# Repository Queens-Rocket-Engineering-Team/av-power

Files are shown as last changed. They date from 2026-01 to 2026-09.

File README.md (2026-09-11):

# Avionics Power Delivery (Power Module, Backplane, Screw Switch, etc)
> 2023-2026 Season - Power Delivery Projects

-  Repo contains board's **firmware**, **schematics**, and related **documentation and datasheets**.
-  The **Main** branch contains current functional hardware/software
-  **Branches** contain board revisions/versions or planned features/fixes.
-  If you're contributing, **make sure you're working in a branch other than Main**

### Folder Structure
- [`/Schematics`](./Schematics/) : PCB design files (KiCad V8)  
- [`/Firmware`](./Firmware/) : Arduino C/C++ code (for STM)
- [`/Datasheets`](./Datasheets/) : Datasheets and reference materials

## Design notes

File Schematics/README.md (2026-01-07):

# Schematics

This directory contains all schematics involved in this iteration of the Avionics Power Deliver system.

## Backplane
- Single, large PCB
- Connects all stack "modules" (PCBs)
- Allows communication between modules
- Cleaner routing for power

## Power Module
- Facilitates connections between backplane and external devices
	- Batteries
	- Screw switches

## Screw switches
- Supports manual enabling of power to avionics via screws
- Connected through Power Module

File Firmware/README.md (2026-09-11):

# Power Module Firmware

This directory contains the firmware for the avionics Power Modules. The module firmware in this directory should be mostly functional.

We currently use the Arduino IDE with the STM32Duino core ("STM32 MCU based boards" by STMicroelectronics, working with 2.7.1) for developing firmware for our modules. We flash firmware to the modules using SWD via an STLinkV2.

## Attributions

Our firmware uses a variety of external libraries. Most libraries can be found through the Arduino library manager, and those that cannot have the corresponding GitHub link beside their include statements. We have taken care not to include any external libraries within our repository; only code we have written (or have modified and credited) are included here.

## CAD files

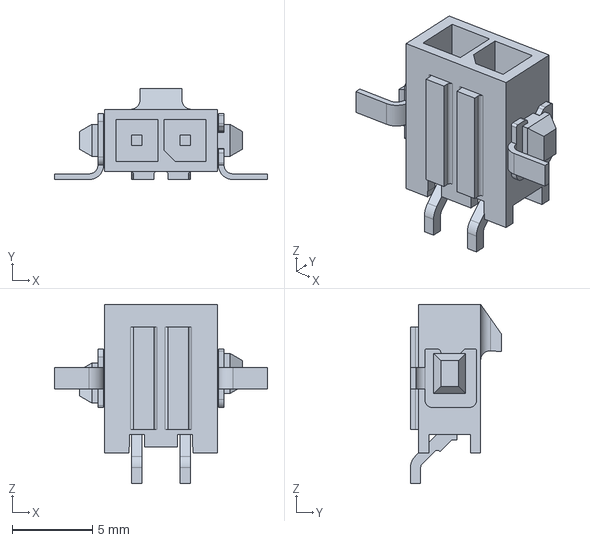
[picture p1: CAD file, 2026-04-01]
Schematics/Hybrid_Power_Module/models/CONN_2-1445057-2_AMP.step
13.2 x 5.67 x 11.2 mm

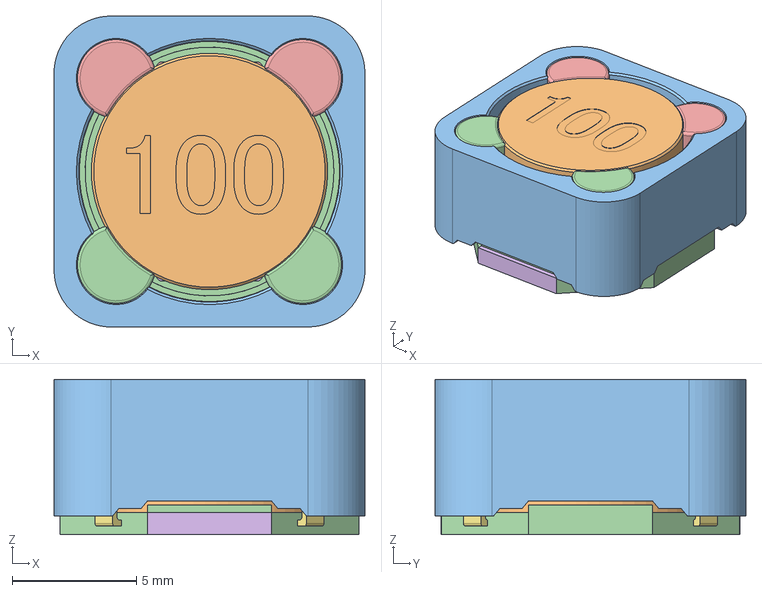
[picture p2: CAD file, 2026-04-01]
Schematics/Power_Module/models/SRR1260A.STP
12.5 x 12.5 x 6.25 mm

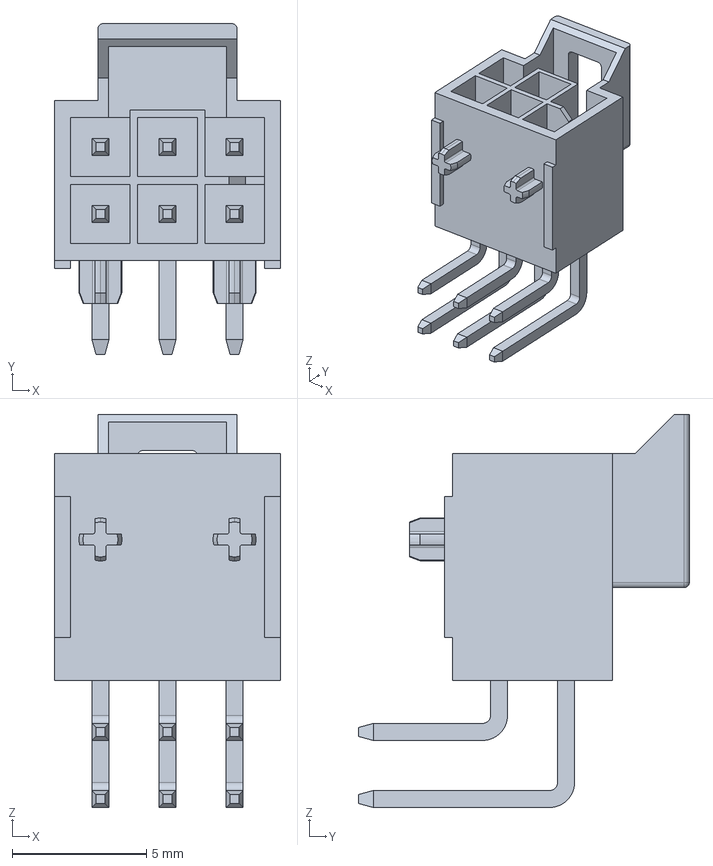
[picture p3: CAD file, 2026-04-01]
Schematics/Hybrid_Backplane/models/1053141106.stp
8.44 x 12.3 x 14.7 mm

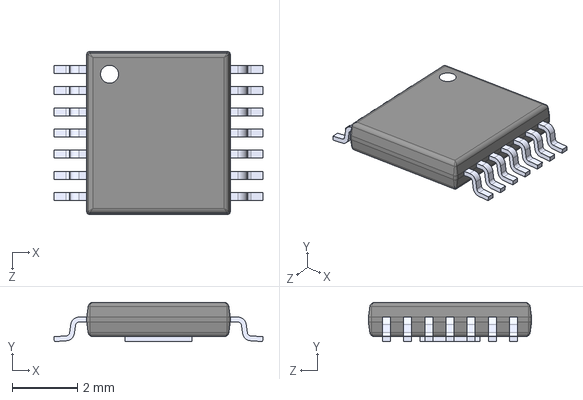
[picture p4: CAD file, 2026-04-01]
Schematics/Power_Module/models/TPS61175PWPR.step
6.40 x 1.20 x 5.00 mm

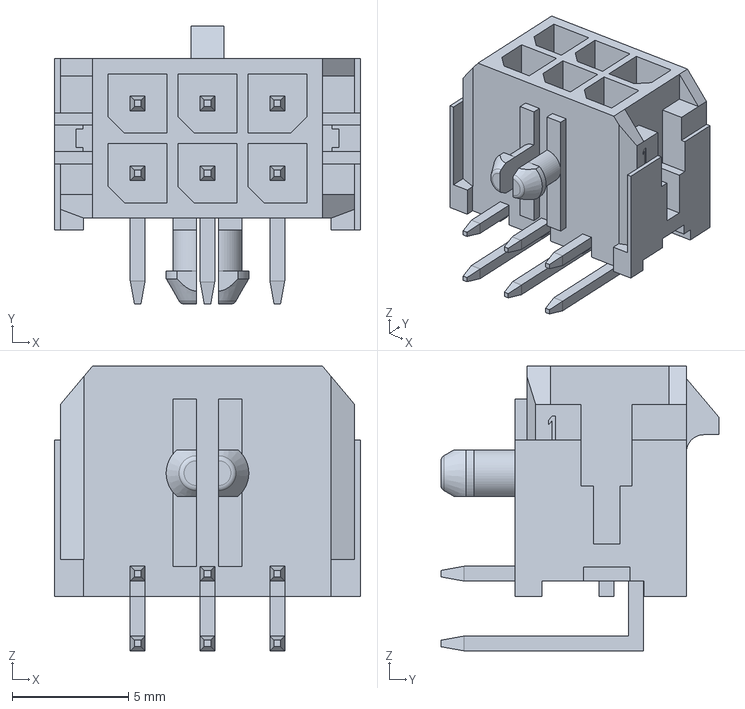
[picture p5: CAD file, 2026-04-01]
Schematics/Hybrid_Backplane/models/430450602.stp
13.2 x 11.9 x 12.2 mm

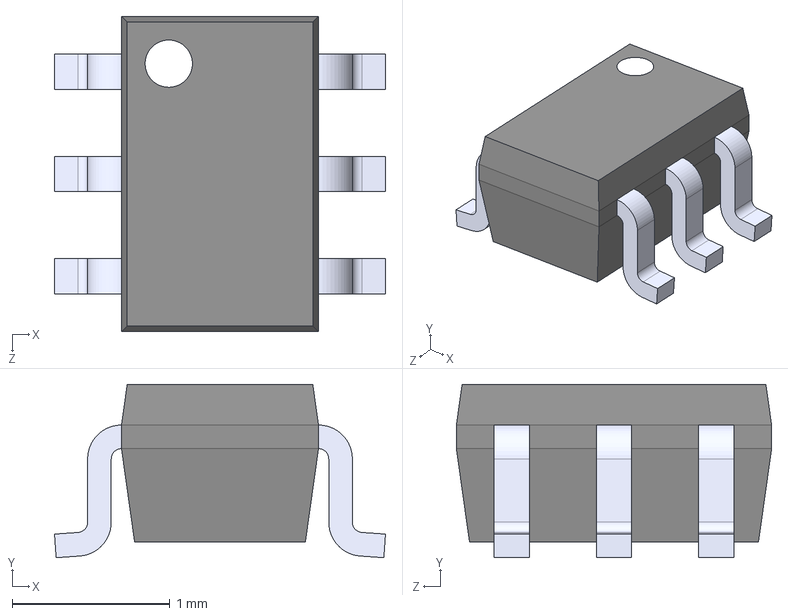
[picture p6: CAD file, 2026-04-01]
Schematics/Hybrid_Power_Module/models/LM66100DCKR.step
2.10 x 1.10 x 2.00 mm

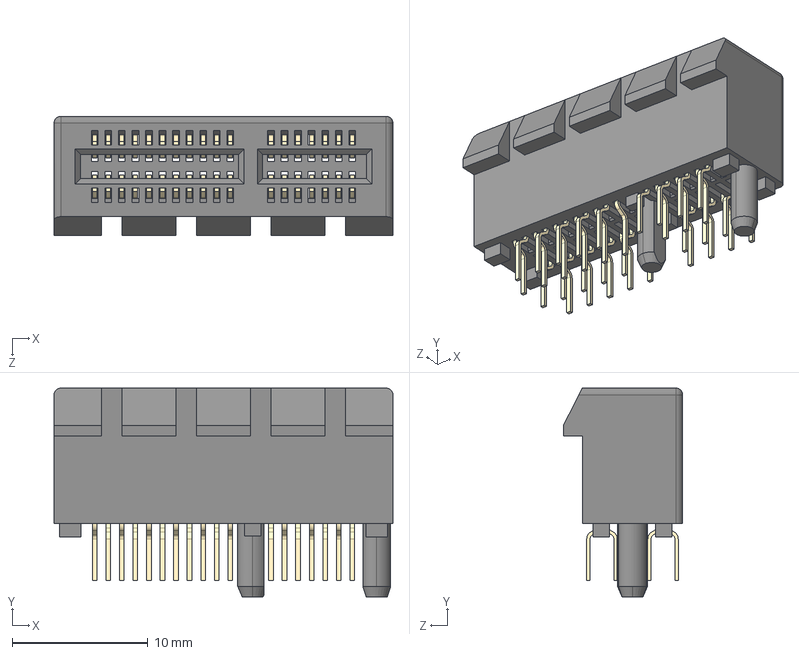
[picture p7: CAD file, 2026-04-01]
Schematics/Hybrid_Backplane/models/10018784-10210TLF.step
25.0 x 15.4 x 8.80 mm

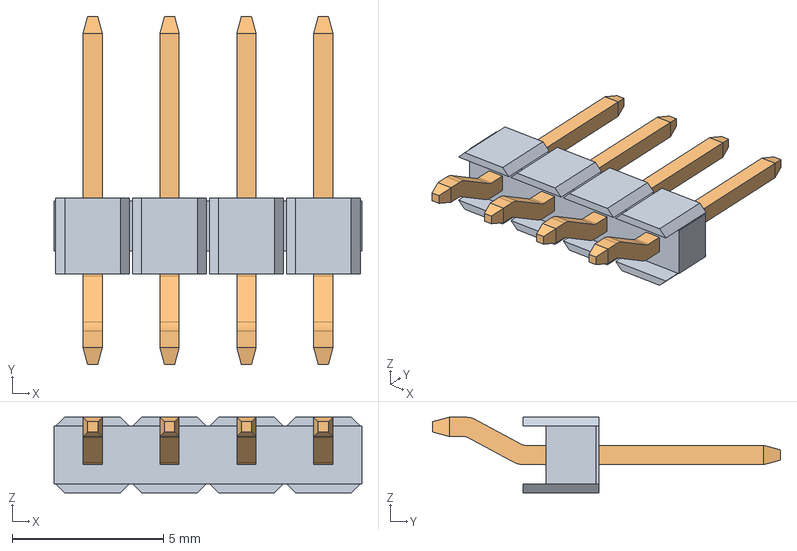
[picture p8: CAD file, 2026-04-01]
Schematics/Hybrid_Power_Module/models/8890445_SWD_PINS.stp
10.2 x 11.5 x 2.50 mm

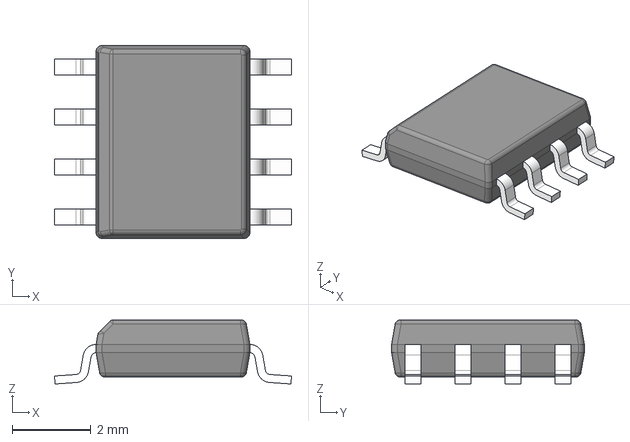
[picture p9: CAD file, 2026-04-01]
Schematics/Hybrid_Power_Module/models/ISO1044BDR.stp
6.02 x 4.90 x 1.63 mm
BODY-SO
LEAD-D0008A x 8

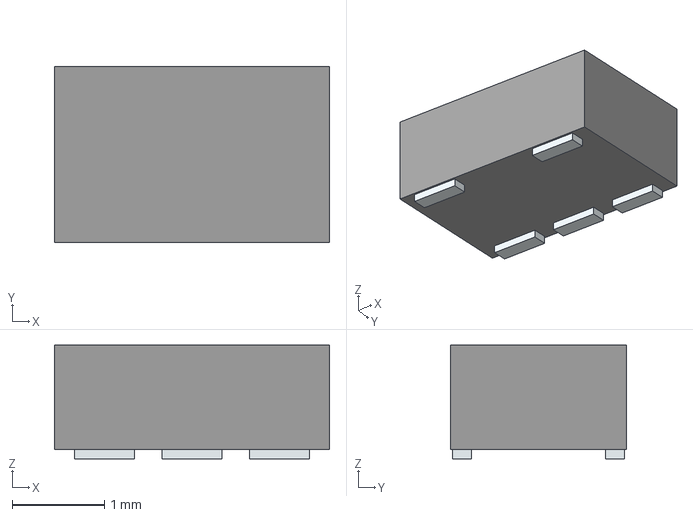
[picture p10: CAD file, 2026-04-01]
Schematics/Hybrid_Power_Module/models/ACS37041KLHBLT-010B3.stp
2.98 x 1.91 x 1.23 mm
Pins

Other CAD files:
Schematics/Hybrid_Power_Module/models/c-2-1445057-2-d-3d.stp
Schematics/Hybrid_Power_Module/models/TPS61175PWPR.step

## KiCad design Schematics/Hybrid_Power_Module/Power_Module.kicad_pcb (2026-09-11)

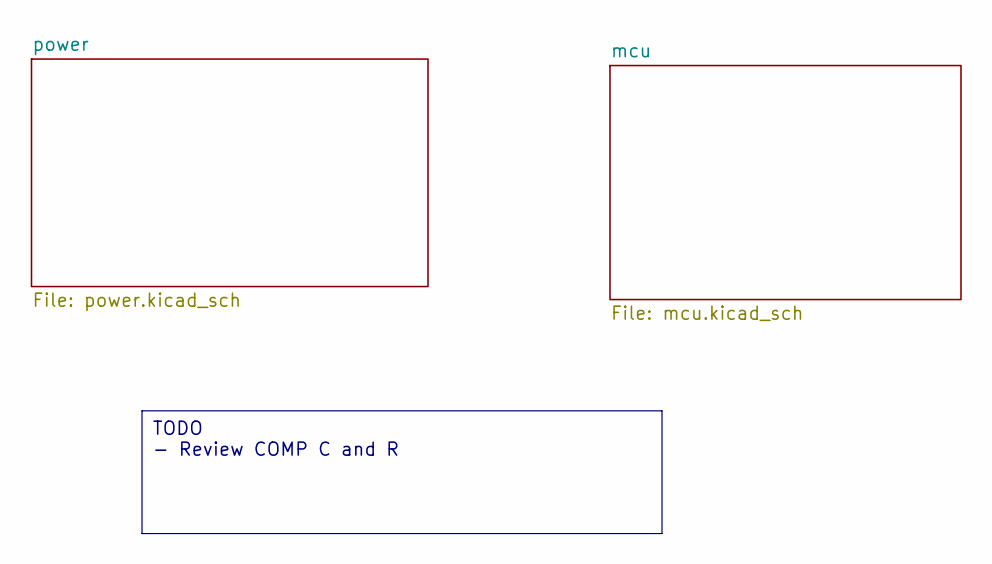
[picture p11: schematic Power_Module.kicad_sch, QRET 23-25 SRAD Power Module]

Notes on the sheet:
TODO - Review COMP C and R

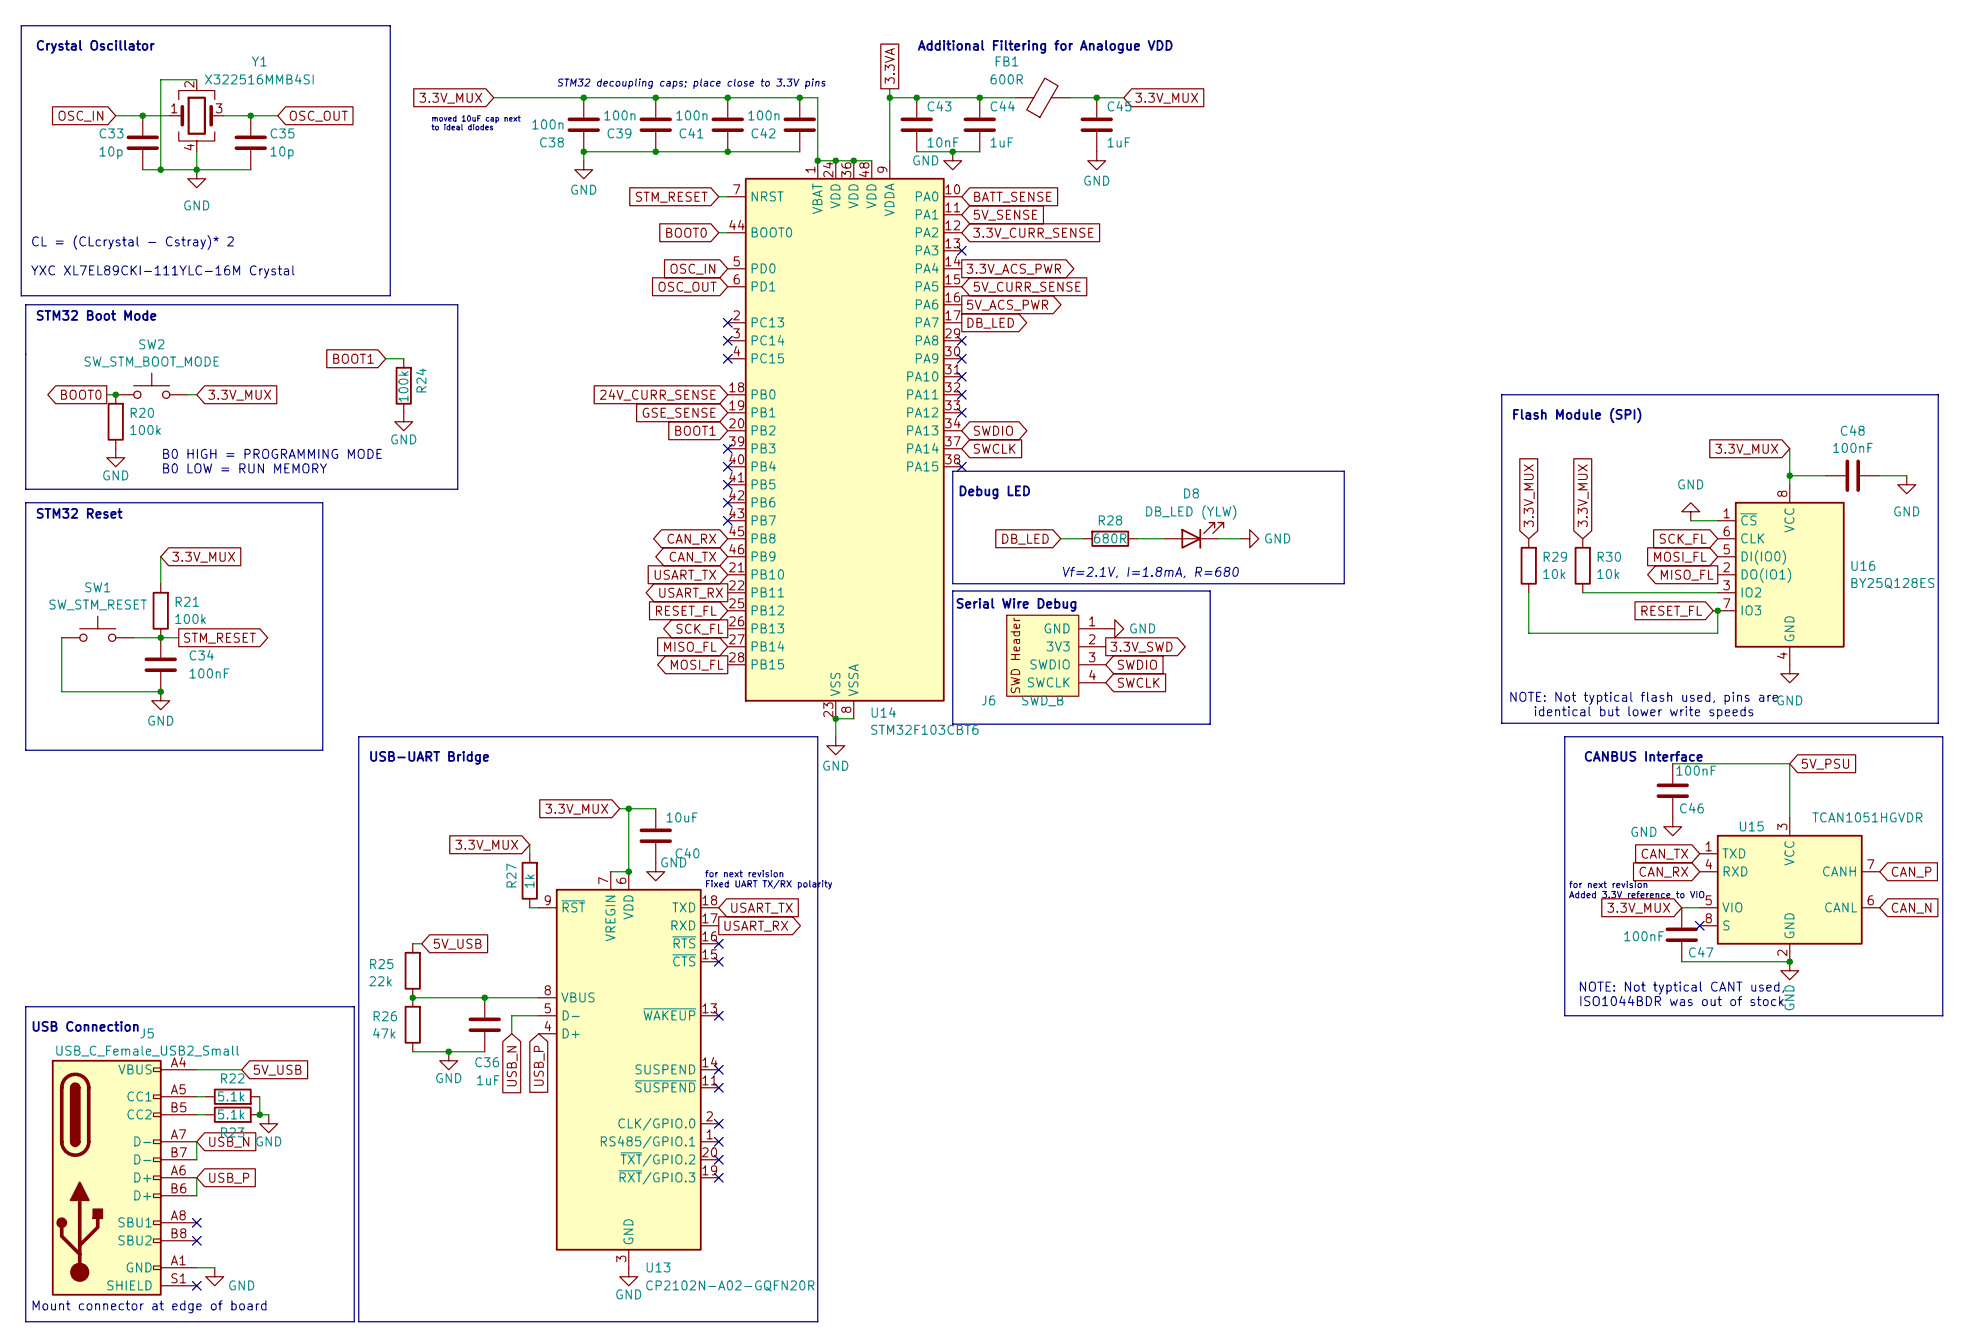
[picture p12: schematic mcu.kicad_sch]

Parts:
C33, C35: 10p; C_0402_1005Metric; LCSC C32949
C34, C46, C47, C48: 100nF; C_0603_1608Metric; LCSC C14663
C36, C44, C45: 1uF; C_0603_1608Metric; LCSC C15849
C38, C39, C41, C42: 100n; C_0402_1005Metric; LCSC C1525
C40: 10uF; C_0603_1608Metric; LCSC C96446
C43: 10nF; C_0603_1608Metric; LCSC C57112
D8: DB_LED (YLW); LED_0603_1608Metric; LCSC C2290
FB1: 600R; L_0603_1608Metric; LCSC C1002
J5: USB_C_Female_USB2_Small; USB_C_DB-108PWB; LCSC C5178541
J6: SWD_B; SWD_PinHeader_1x04_P2.54mm_Horizontal_SMD; Digikey 952-3233-ND
R20, R21, R24: 100k; R_0603_1608Metric; LCSC C25803
R22, R23: 5.1k; R_0603_1608Metric; LCSC C23186
R25: 22k; R_0603_1608Metric; LCSC C31850
R26: 47k; R_0603_1608Metric; LCSC C25819
R27: 1k; R_0603_1608Metric; LCSC C21190
R28: 680R; R_0603_1608Metric; LCSC C23228
R29, R30: 10k; R_0603_1608Metric; LCSC C25804
SW1: SW_STM_RESET; SW_Push_1P1T_XKB_TS-1187A; LCSC C318884
SW2: SW_STM_BOOT_MODE; SW_Push_1P1T_XKB_TS-1187A; LCSC C318884
U13: CP2102N-A02-GQFN20R; QFN-20-1EP_3x3mm; LCSC C969913
U14: STM32F103CBT6; LQFP-48_7x7mm_P0.5mm; LCSC C8304
U15: TCAN1051HGVDR; SOIC_1044BDR_TEX; Digikey 296-44225-1-ND
U16: BY25Q128ES; SOIC-8_5.23x5.23mm_P1.27mm; Digikey 5369-BY25Q128ESSIG(R)CT-ND
Y1: X322516MMB4SI; Crystal_SMD_3225-4Pin_3.2x2.5mm; LCSC C13738

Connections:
3.3VA: C43.1, C44.1, FB1.1, U14.9 (VDDA)
3.3V_ACS_PWR: U14.14 (PA4); also elsewhere on the board
3.3V_CURR_SENSE: U14.12 (PA2); also elsewhere on the board
3.3V_MUX: C38.2, C39.2, C40.1, C41.2, C42.2, C45.1, C47.1, C48.1, FB1.2, R21.2, R27.2, R29.2, R30.2, SW2.2, U13.6 (VDD), U13.7 (VREGIN), U14.1 (VBAT), U14.24 (VDD), U14.36 (VDD), U14.48 (VDD), U15.5 (VIO), U16.8 (VCC); also elsewhere on the board
3.3V_SWD: J6.2 (3V3); also elsewhere on the board
5V_ACS_PWR: U14.16 (PA6); also elsewhere on the board
5V_CURR_SENSE: U14.15 (PA5); also elsewhere on the board
5V_PSU: C46.1, U15.3 (VCC); also elsewhere on the board
5V_SENSE: U14.11 (PA1); also elsewhere on the board
5V_USB: J5.A4 (VBUS), J5.A9 (VBUS), J5.B4 (VBUS), J5.B9 (VBUS), R25.2; also elsewhere on the board
24V_CURR_SENSE: U14.18 (PB0); also elsewhere on the board
BATT_SENSE: U14.10 (PA0); also elsewhere on the board
BOOT0: R20.2, SW2.1, U14.44 (BOOT0)
BOOT1: R24.2, U14.20 (PB2)
CAN_N: U15.6 (CANL); also elsewhere on the board
CAN_P: U15.7 (CANH); also elsewhere on the board
CAN_RX: U14.45 (PB8), U15.4 (RXD)
CAN_TX: U14.46 (PB9), U15.1 (TXD)
DB_LED: R28.2, U14.17 (PA7)
GND: C33.2, C34.2, C35.2, C36.1, C38.1, C39.1, C40.2, C41.1, C42.1, C43.2, C44.2, C45.2, C46.2, C47.2, C48.2, D8.1 (K), J5.A1 (GND), J5.A12 (GND), J5.B1 (GND), J5.B12 (GND), J6.1 (GND), R20.1, R22.2, R23.2, R24.1, R26.1, SW1.1, U13.3 (GND), U13.12 (GND), U13.21 (GND), U14.8 (VSSA), U14.23 (VSS), U14.35 (VSS), U14.47 (VSS), U15.2 (GND), U16.1 (~CS), U16.4 (GND), Y1.2, Y1.4; also elsewhere on the board
GSE_SENSE: U14.19 (PB1); also elsewhere on the board
MISO_FL: U14.27 (PB14), U16.2 (DO(IO1))
MOSI_FL: U14.28 (PB15), U16.5 (DI(IO0))
unnamed: D8.2 (A), R28.1
unnamed: J5.A5 (CC1), R22.1
unnamed: J5.B5 (CC2), R23.1
unnamed: C36.2, R25.1, R26.2, U13.8 (VBUS)
unnamed: R27.1, U13.9 (~RST)
unnamed: R30.1, U16.3 (IO2)
OSC_IN: C33.1, U14.5 (PD0), Y1.1
OSC_OUT: C35.1, U14.6 (PD1), Y1.3
RESET_FL: R29.1, U14.25 (PB12), U16.7 (IO3)
SCK_FL: U14.26 (PB13), U16.6 (CLK)
STM_RESET: C34.1, R21.1, SW1.2, U14.7 (NRST)
SWCLK: J6.4 (SWCLK), U14.37 (PA14)
SWDIO: J6.3 (SWDIO), U14.34 (PA13)
USART_RX: U13.17 (RXD), U14.22 (PB11)
USART_TX: U13.18 (TXD), U14.21 (PB10)
USB_N: J5.A7 (D-), J5.B7 (D-), U13.5 (D-)
USB_P: J5.A6 (D+), J5.B6 (D+), U13.4 (D+)

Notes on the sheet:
STM32 Reset
STM32 decoupling caps; place close to 3.3V pins
NOTE: Not typtical CANT used, ISO1044BDR was out of stock
Vf=2.1V, I=1.8mA, R=680
CANBUS Interface
for next revision Fixed UART TX/RX polarity
Flash Module (SPI)
NOTE: Not typtical flash used, pins are identical but lower write speeds
Serial Wire Debug
Debug LED
B0 HIGH = PROGRAMMING MODE B0 LOW = RUN MEMORY
USB-UART Bridge
CL = (CLcrystal - Cstray)* 2 YXC XL7EL89CKI-111YLC-16M Crystal
Mount connector at edge of board
Crystal Oscillator
for next revision Added 3.3V reference to VIO
moved 10uF cap next to ideal diodes
STM32 Boot Mode
USB Connection
Additional Filtering for Analogue VDD

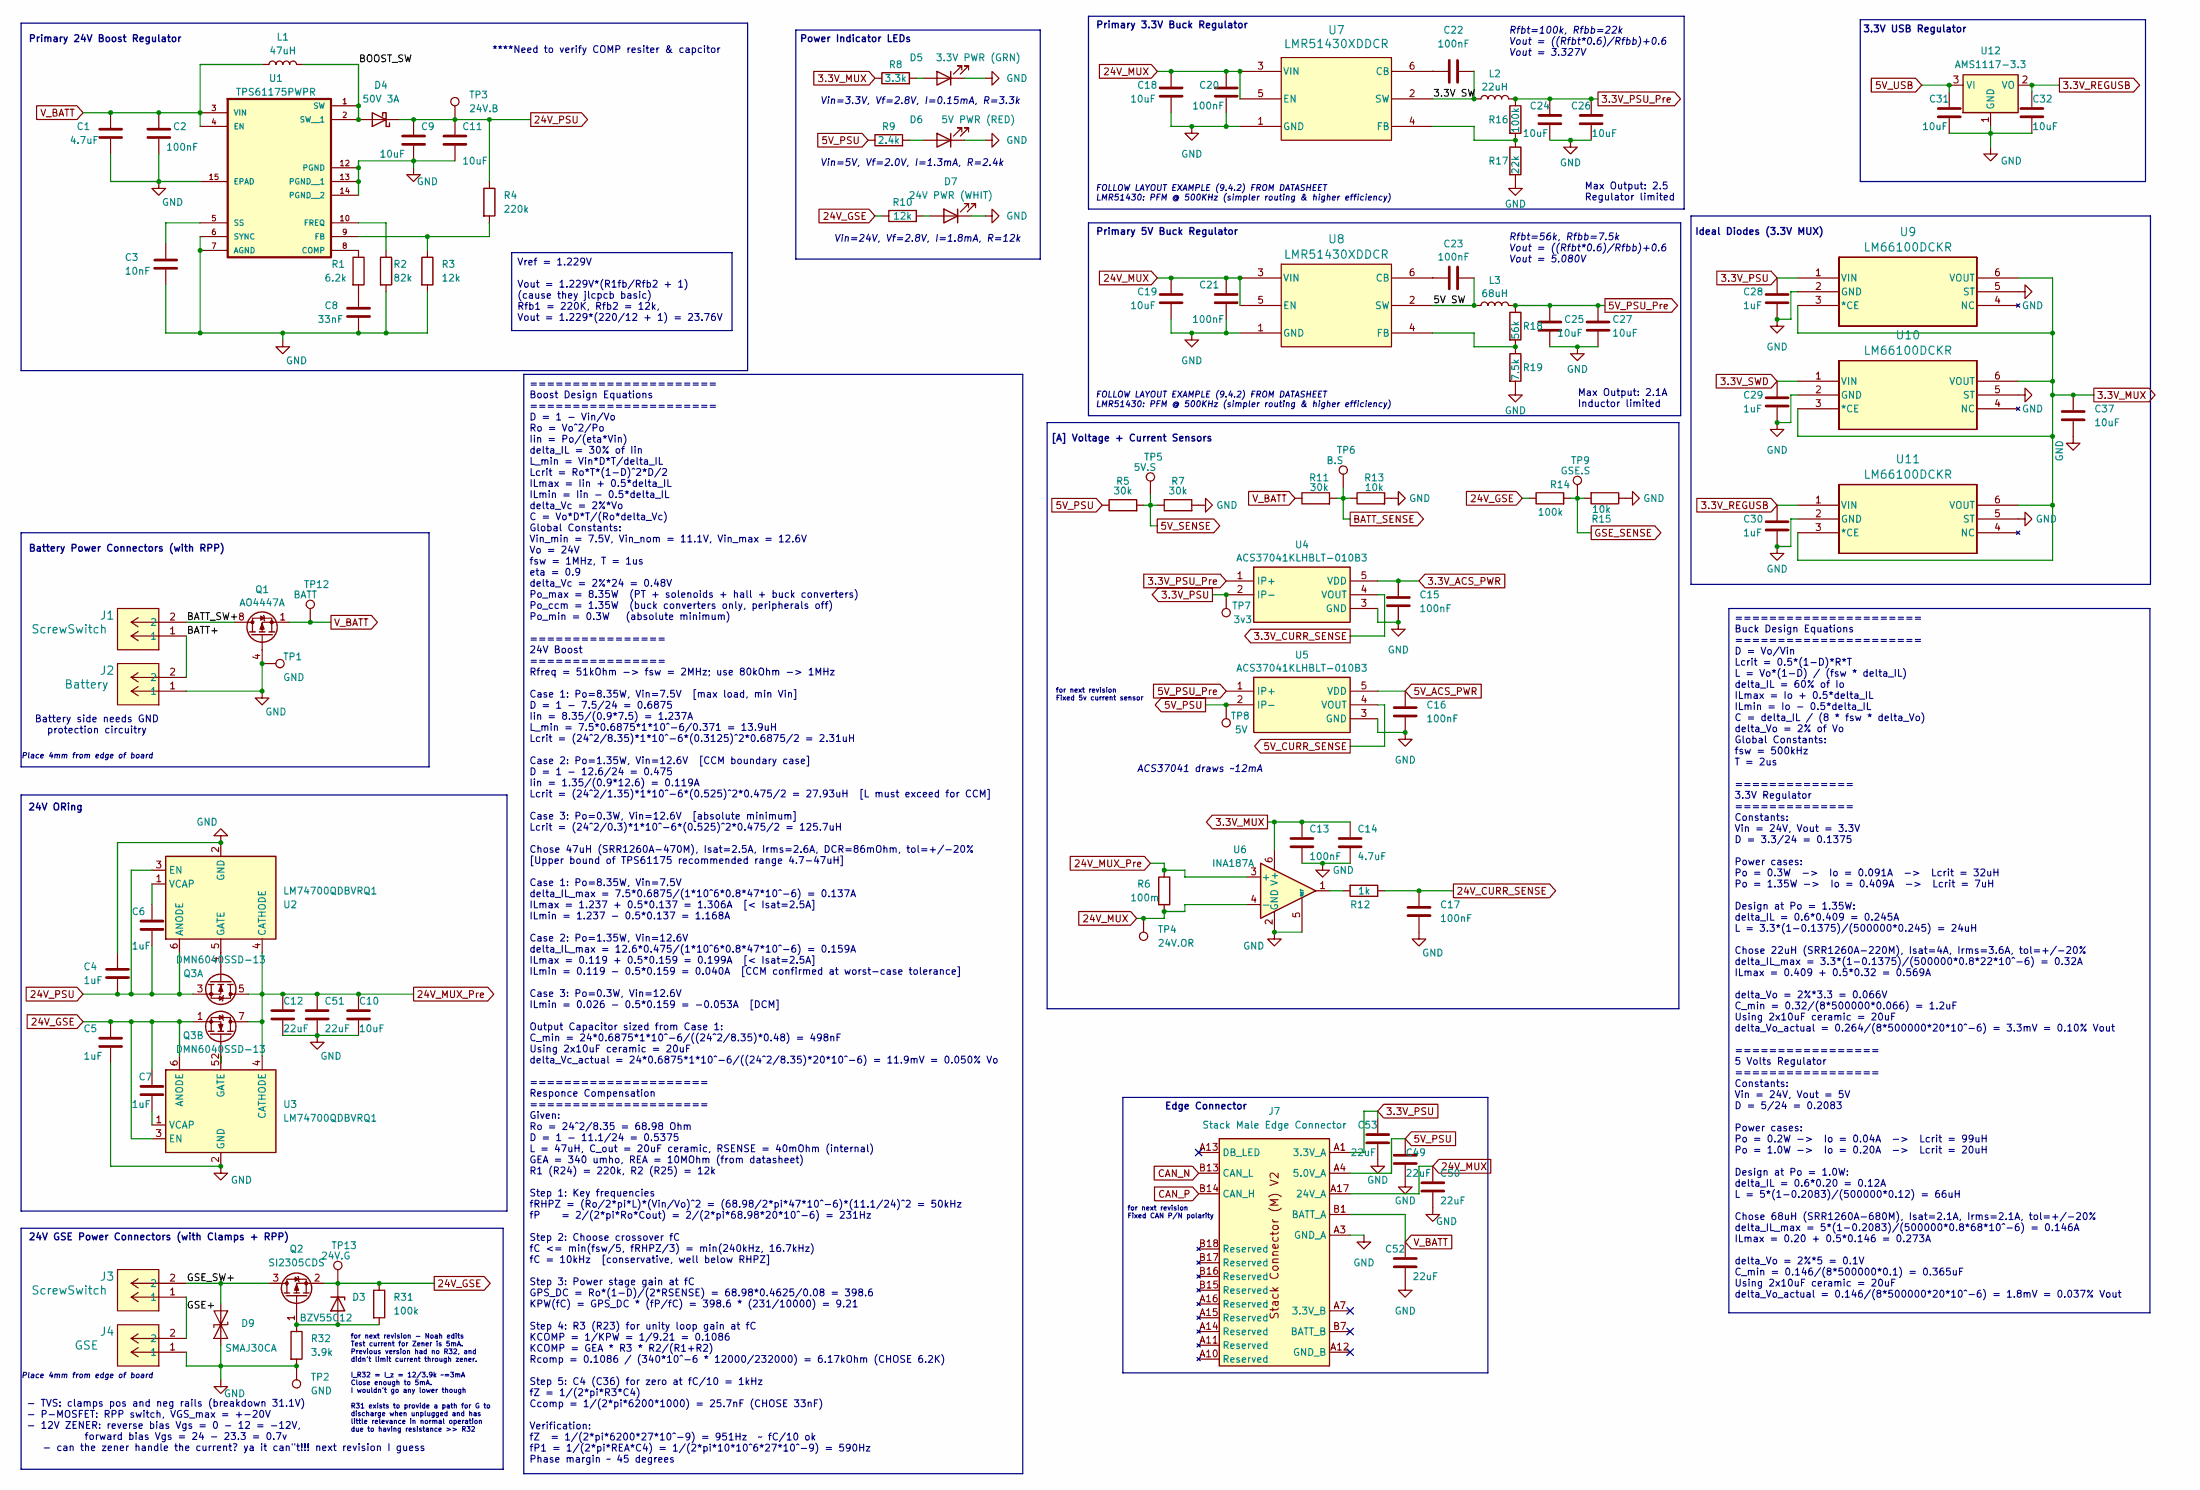
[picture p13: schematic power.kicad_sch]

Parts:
C1, C14: 4.7uF; C_0805_2012Metric; LCSC C1779
C2, C13, C15, C16, C17, C20, C21, C22, C23: 100nF; C_0603_1608Metric; LCSC C14663
C3: 10nF; C_0603_1608Metric; LCSC C57112
C4, C5, C6, C7, C28, C29, C30: 1uF; C_0603_1608Metric; LCSC C15849
C8: 33nF; C_0603_1608Metric; LCSC C21117
C9, C10, C11, C18, C19: 10uF; C_1206_3216Metric; LCSC C13585
C12, C50, C51: 22uF; C_1206_3216Metric; Digikey 445-8045-1-ND
C24, C25, C26, C27, C37: 10uF; C_0805_2012Metric; LCSC C15850
C31, C32: 10uF; C_0603_1608Metric; LCSC C96446
C49, C52, C53: 22uF; C_1206_3216Metric; LCSC C12891
D3: BZV55C12; D_MiniMELF; LCSC C545360
D4: 50V 3A; D_SMA; Digikey 112-VSSAF5N50-M3/6BCT-ND
D5: 3.3V PWR (GRN); LED_0805_2012Metric; LCSC C2297
D6: 5V PWR (RED); LED_0805_2012Metric; LCSC C84256
D7: 24V PWR (WHIT); LED_0805_2012Metric; LCSC C34499
D9: SMAJ30CA; D_SMA; LCSC C110043
J1, J3: ScrewSwitch; CONN_2-1445057-2_TYCO; Digikey A33212CT-ND
J2: Battery; CONN_2-1445057-2_TYCO; Digikey A33212CT-ND
J4: GSE; CONN_2-1445057-2_TYCO; Digikey A33212CT-ND
J7: Stack Male Edge Connector; BUS_PCIexpress_x1
L1: 47uH; L_Bourns_SRN8040TA; Digikey 283-SDCHA1V8040-470-RCT-ND
L2: 22uH; L_Bourns_SRN8040TA; Digikey 283-SDCHA1V8040-220-RCT-ND
L3: 68uH; L_Bourns_SRN8040TA; Digikey 283-SDCHA1V8040-680-RCT-ND
Q1: AO4447A; SOIC-8_3.9x4.9mm_P1.27mm; LCSC C125867
Q2: SI2305CDS; SOT-23; LCSC C5182095
Q3: DMN6040SSD-13; SOIC-8_3.9x4.9mm_P1.27mm; LCSC C154876
R1: 6.2k; R_0603_1608Metric; LCSC C4260
R2: 82k; R_0603_1608Metric; LCSC C23254
R3, R10: 12k; R_0603_1608Metric; LCSC C22790
R4: 220k; R_0603_1608Metric; LCSC C22961
R5, R7, R11: 30k; R_0603_1608Metric; LCSC C22984
R6: 100m; R_1206_3216Metric_Pad1.30x1.75mm_HandSolder; Digikey P18940CT-ND
R8: 3.3k; R_0603_1608Metric; LCSC C22978
R9: 2.4k; R_0603_1608Metric; LCSC C22940
R12: 1k; R_0603_1608Metric; LCSC C21190
R13, R15: 10k; R_0603_1608Metric; LCSC C25804
R14, R16: 100k; R_0603_1608Metric; LCSC C25803
R17: 22k; R_0603_1608Metric; LCSC C31850
R18: 56k; R_0603_1608Metric; LCSC C23206
R19: 7.5k; R_0603_1608Metric; LCSC C23234
R31: 100k; R_0603_1608Metric; LCSC C23260
R32: 3.9k; R_0603_1608Metric; LCSC C22809
TP1, TP2: GND; TestPoint_Pad_1.5x1.5mm
TP3: 24V.B; TestPoint_Pad_1.5x1.5mm
TP4: 24V.OR; TestPoint_Pad_1.5x1.5mm
TP5: 5V.S; TestPoint_Pad_1.5x1.5mm
TP6: B.S; TestPoint_Pad_1.5x1.5mm
TP7: 3v3; TestPoint_Pad_1.5x1.5mm
TP8: 5V; TestPoint_Pad_1.5x1.5mm
TP9: GSE.S; TestPoint_Pad_1.5x1.5mm
TP12: BATT; TestPoint_Pad_1.5x1.5mm
TP13: 24V.G; TestPoint_Pad_1.5x1.5mm
U1: TPS61175PWPR; IC_TPS27S100BPWPR; Digikey 296-24013-1-ND
U2, U3: LM74700QDBVRQ1; SOT-23-6; LCSC C2941042
U4, U5: ACS37041KLHBLT-010B3; APS12628LLHALTBAP_HandSolder; Digikey 620-ACS37041KLHBLT-010B3CT-ND
U6: INA187A; SOT-23-6; Digikey 296-INA187A1IDBVRCT-ND
U7, U8: LMR51430XDDCR; SOT-23-6_Handsoldering; Digikey 296-LMR51430XDDCRCT-ND
U9, U10, U11: LM66100DCKR; SC-70-6; LCSC C2869734
U12: AMS1117-3.3; SOT-223-3_TabPin2; LCSC C6186

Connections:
3.3V_ACS_PWR: C15.1, U4.5 (VDD); also elsewhere on the board
3.3V_CURR_SENSE: U4.4 (VOUT); also elsewhere on the board
3.3V_MUX: C13.1, C14.1, C37.1, R8.1, U6.6 (V+), U9.3 (*CE), U9.6 (VOUT), U10.3 (*CE), U10.6 (VOUT), U11.3 (*CE), U11.6 (VOUT); also elsewhere on the board
3.3V_PSU: C28.1, C53.1, J7.A1 (3.3V_A), J7.A2 (3.3V_A), TP7.1 (1_1), U4.2 (IP-), U9.1 (VIN)
3.3V_PSU_Pre: C24.1, C26.1, L2.1, R16.1, U4.1 (IP+)
3.3V_REGUSB: C30.1, C32.1, U11.1 (VIN), U12.2 (VO)
3.3V_SWD: C29.1, U10.1 (VIN); also elsewhere on the board
5V_ACS_PWR: C16.1, U5.5 (VDD); also elsewhere on the board
5V_CURR_SENSE: U5.4 (VOUT); also elsewhere on the board
5V_PSU: C49.1, J7.A4 (5.0V_A), J7.A5 (5.0V_A), R5.1, R9.1, TP8.1 (1_1), U5.2 (IP-); also elsewhere on the board
5V_PSU_Pre: C25.1, C27.1, L3.2, R18.1, U5.1 (IP+)
5V_SENSE: R5.2, R7.1, TP5.1 (1_1); also elsewhere on the board
5V_USB: C31.1, U12.3 (VI); also elsewhere on the board
24V_CURR_SENSE: C17.1, R12.1; also elsewhere on the board
24V_GSE: C5.1, C7.1, D3.1 (K), Q2.2 (S), Q3.1 (S1), R10.1, R14.1, R31.1, TP13.1 (1_1), U3.3 (EN), U3.6 (ANODE)
24V_MUX: C18.1, C19.1, C20.1, C21.1, C50.1, J7.A17 (24V_A), J7.A18 (24V_A), R6.2, TP4.1 (1_1), U6.4 (-), U7.3 (VIN), U7.5 (EN), U8.3 (VIN), U8.5 (EN)
24V_MUX_Pre: C10.1, C12.1, C51.1, Q3.5 (D2), Q3.6 (D2), Q3.7 (D1), Q3.8 (D1), R6.1, U2.4 (CATHODE), U3.4 (CATHODE), U6.3 (+)
24V_PSU: C4.2, C6.2, C9.1, C11.1, D4.1 (K), Q3.3 (S2), R4.1, TP3.1 (1_1), U2.3 (EN), U2.6 (ANODE)
/power/3.3V SW: C22.2, L2.2, U7.2 (SW)
/power/5V SW: C23.1, L3.1, U8.2 (SW)
/power/BATT+: J1.1, J2.2
/power/BATT_SW+: J1.2, Q1.5 (D), Q1.6 (D), Q1.7 (D), Q1.8 (D)
/power/BOOST_SW: D4.2 (A), L1.2, U1.1 (SW), U1.2 (SW__1)
/power/GSE+: J3.1, J4.2
/power/GSE_SW+: D9.2 (A2), J3.2, Q2.3 (D)
BATT_SENSE: R11.2, R13.1, TP6.1 (1_1); also elsewhere on the board
CAN_N: J7.B13 (CAN_L); also elsewhere on the board
CAN_P: J7.B14 (CAN_H); also elsewhere on the board
GND: C1.2, C2.2, C3.2, C4.1, C5.2, C8.2, C9.2, C10.2, C11.2, C12.2, C13.2, C14.2, C15.2, C16.2, C17.2, C18.2, C19.2, C20.2, C21.2, C24.2, C25.2, C26.2, C27.2, C28.2, C29.2, C30.2, C31.2, C32.2, C37.2, C49.2, C50.2, C51.2, C52.2, C53.2, D5.1 (K), D6.1 (K), D7.1 (K), D9.1 (A1), J2.1, J4.1, J7.A3 (GND_A), J7.A6 (GND_A), J7.B4 (GND_A), J7.B5 (GND_A), J7.B6 (GND_A), Q1.4 (G), R2.2, R3.2, R7.2, R13.2, R15.1, R17.2, R19.2, R32.2, TP1.1 (1_1), TP2.1 (1_1), U1.6 (SYNC), U1.7 (AGND), U1.12 (PGND), U1.13 (PGND__1), U1.14 (PGND__2), U1.15 (EPAD), U2.2 (GND), U3.2 (GND), U4.3 (GND), U5.3 (GND), U6.2 (GND), U6.5 (REF), U7.1 (GND), U8.1 (GND), U9.2 (GND), U9.5 (ST), U10.2 (GND), U10.5 (ST), U11.2 (GND), U11.5 (ST), U12.1 (GND); also elsewhere on the board
GSE_SENSE: R14.2, R15.2, TP9.1 (1_1); also elsewhere on the board
unnamed: C8.1, R1.2
unnamed: D3.2 (A), Q2.1 (G), R31.2, R32.1
unnamed: D5.2 (A), R8.2
unnamed: D6.2 (A), R9.2
unnamed: D7.2 (A), R10.2
unnamed: Q3.2 (G1), U3.5 (GATE)
unnamed: Q3.4 (G2), U2.5 (GATE)
unnamed: R12.2, U6.1
unnamed: R1.1, U1.8 (COMP)
unnamed: R3.1, R4.2, U1.9 (FB)
unnamed: R2.1, U1.10 (FREQ)
unnamed: C3.1, U1.5 (SS)
unnamed: C6.1, U2.1 (VCAP)
unnamed: C7.2, U3.1 (VCAP)
unnamed: C22.1, U7.6 (CB)
unnamed: R16.2, R17.1, U7.4 (FB)
unnamed: C23.2, U8.6 (CB)
unnamed: R18.2, R19.1, U8.4 (FB)
V_BATT: C1.1, C2.1, C52.1, J7.B1 (BATT_A), J7.B2 (BATT_A), J7.B3 (BATT_A), L1.1, Q1.1 (S), Q1.2 (S), Q1.3 (S), R11.1, TP12.1 (1_1), U1.3 (VIN), U1.4 (EN)

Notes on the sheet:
for next revision Fixed CAN P/N polarity
Vin=3.3V, Vf=2.8V, I=0.15mA, R=3.3k
for next revision Fixed 5v current sensor
Power Indicator LEDs
24V GSE Power Connectors (with Clamps + RPP)
[A] Voltage + Current Sensors
ACS37041 draws ~12mA
FOLLOW LAYOUT EXAMPLE (9.4.2) FROM DATASHEET LMR51430: PFM @ 500KHz (simpler routing & higher efficiency)
Ideal Diodes (3.3V MUX)
Primary 24V Boost Regulator
****Need to verify COMP resiter & capcitor
3.3V USB Regulator
Max Output: 2.5 Regulator limited
for next revision - Noah edits Test current for Zener is 5mA. Previous version had no R32, and didn't limit current through zener. I_R32 = I_z = 12/3.9k ~=3mA Close enough to 5mA. I wouldn't go any lower though R31 exists to provide a path for G to discharge when unplugged and has little relevance 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
Battery Power Connectors (with RPP)
Place 4mm from edge of board
Max Output: 2.1A Inductor limited
Primary 3.3V Buck Regulator
Rfbt=100k, Rfbb=22k Vout = ((Rfbt*0.6)/Rfbb)+0.6 Vout = 3.327V
Rfbt=56k, Rfbb=7.5k Vout = ((Rfbt*0.6)/Rfbb)+0.6 Vout = 5.080V
24V ORing
Vin=5V, Vf=2.0V, I=1.3mA, R=2.4k
Battery side needs GND protection circuitry
- TVS: clamps pos and neg rails (breakdown 31.1V) - P-MOSFET: RPP switch, VGS_max = +-20V - 12V ZENER: reverse bias Vgs = 0 - 12 = -12V, forward bias Vgs = 24 - 23.3 = 0.7v - can the zener handle the current? ya it can"t!!! next revision I guess
Vin=24V, Vf=2.8V, I=1.8mA, R=12k
Edge Connector
Primary 5V Buck Regulator
Vref = 1.229V Vout = 1.229V*(R1fb/Rfb2 + 1) (cause they jlcpcb basic) Rfb1 = 220K, Rfb2 = 12k, Vout = 1.229*(220/12 + 1) = 23.76V
====================== Boost Design Equations ====================== D = 1 - Vin/Vo Ro = Vo^2/Po Iin = Po/(eta*Vin) delta_IL = 30% of Iin L_min = Vin*D*T/delta_IL Lcrit = Ro*T*(1-D)^2*D/2 ILmax = Iin + 0.5*delta_IL ILmin = Iin - 0.5*delta_IL delta_Vc = 2%*Vo C = Vo*D*T/(Ro*delta_Vc) Global Constant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
====================== Buck Design Equations ====================== D = Vo/Vin Lcrit = 0.5*(1-D)*R*T L = Vo*(1-D) / (fsw * delta_IL) delta_IL = 60% of Io ILmax = Io + 0.5*delta_IL ILmin = Io - 0.5*delta_IL C = delta_IL / (8 * fsw * delta_Vo) delta_Vo = 2% of Vo Global Constants: fsw = 500kHz T = 2u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

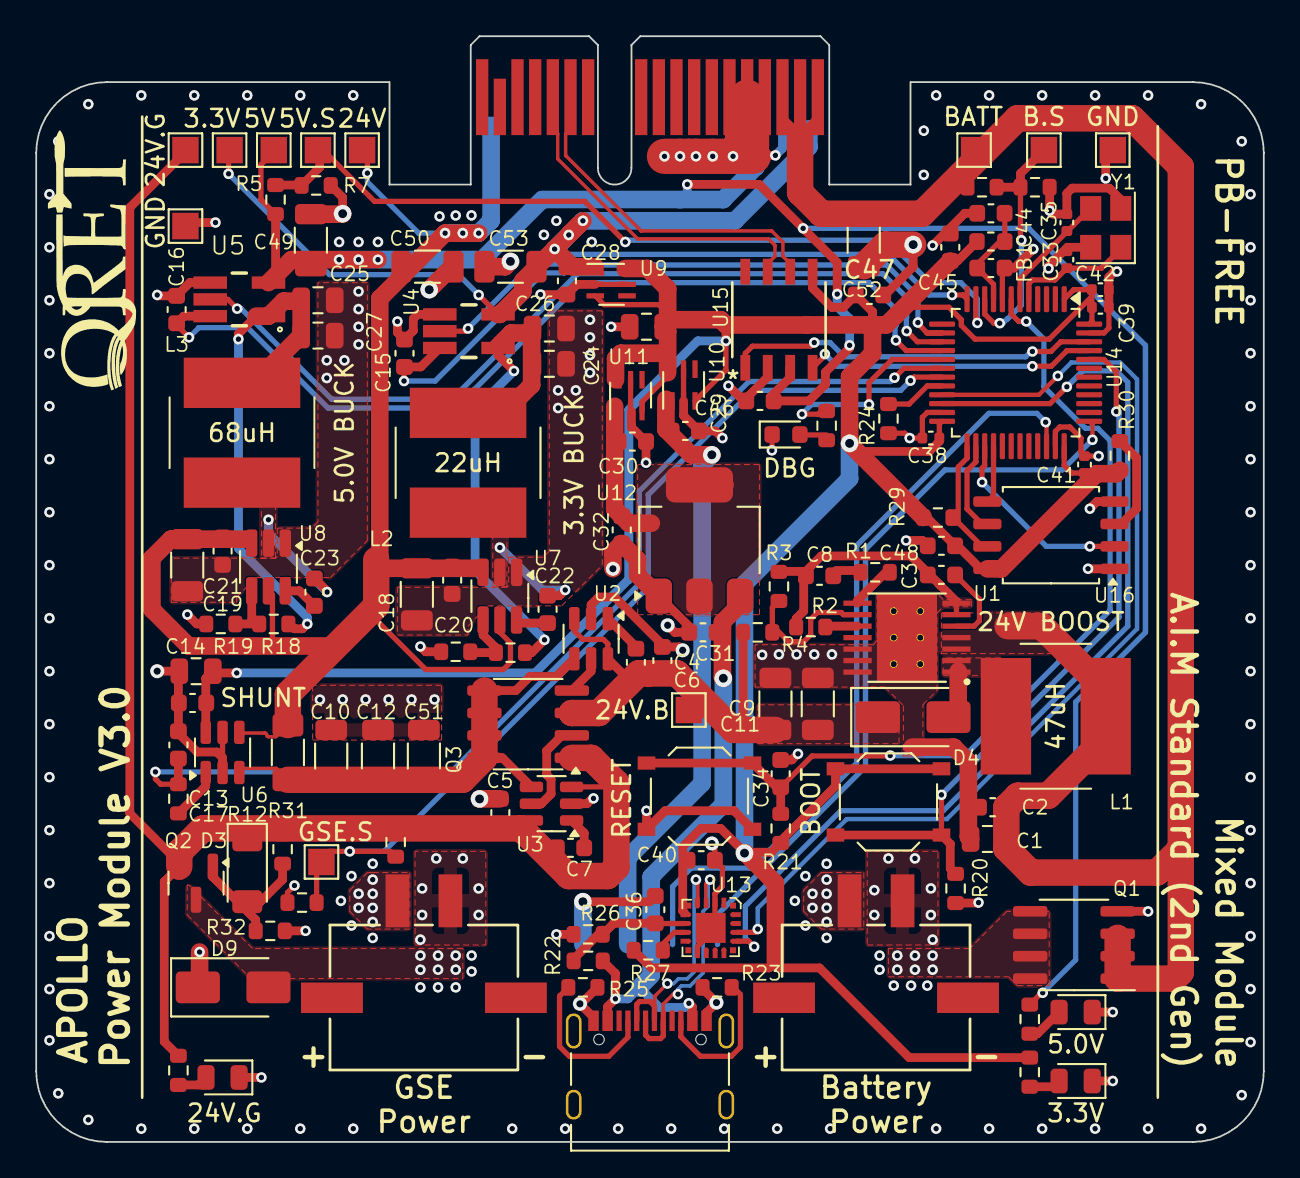
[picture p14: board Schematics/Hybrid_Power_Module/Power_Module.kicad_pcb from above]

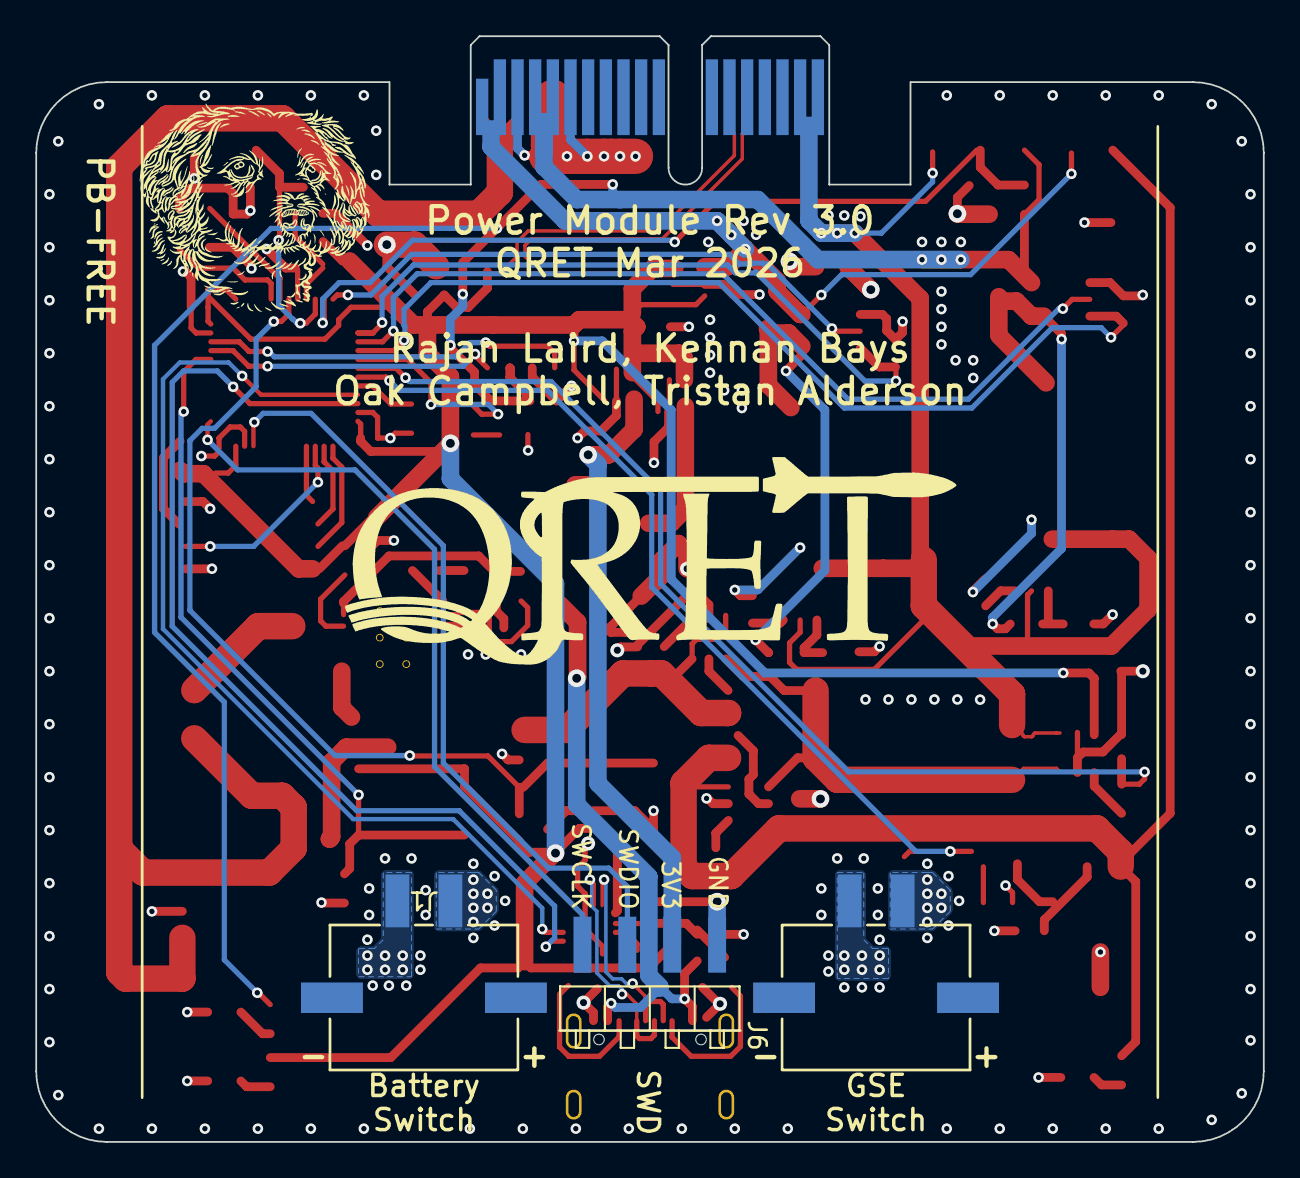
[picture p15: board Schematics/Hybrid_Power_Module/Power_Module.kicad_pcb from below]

Board: 4 copper layers, 69.5 x 62.6 mm, 136 parts (3 on the bottom side), 74 nets.

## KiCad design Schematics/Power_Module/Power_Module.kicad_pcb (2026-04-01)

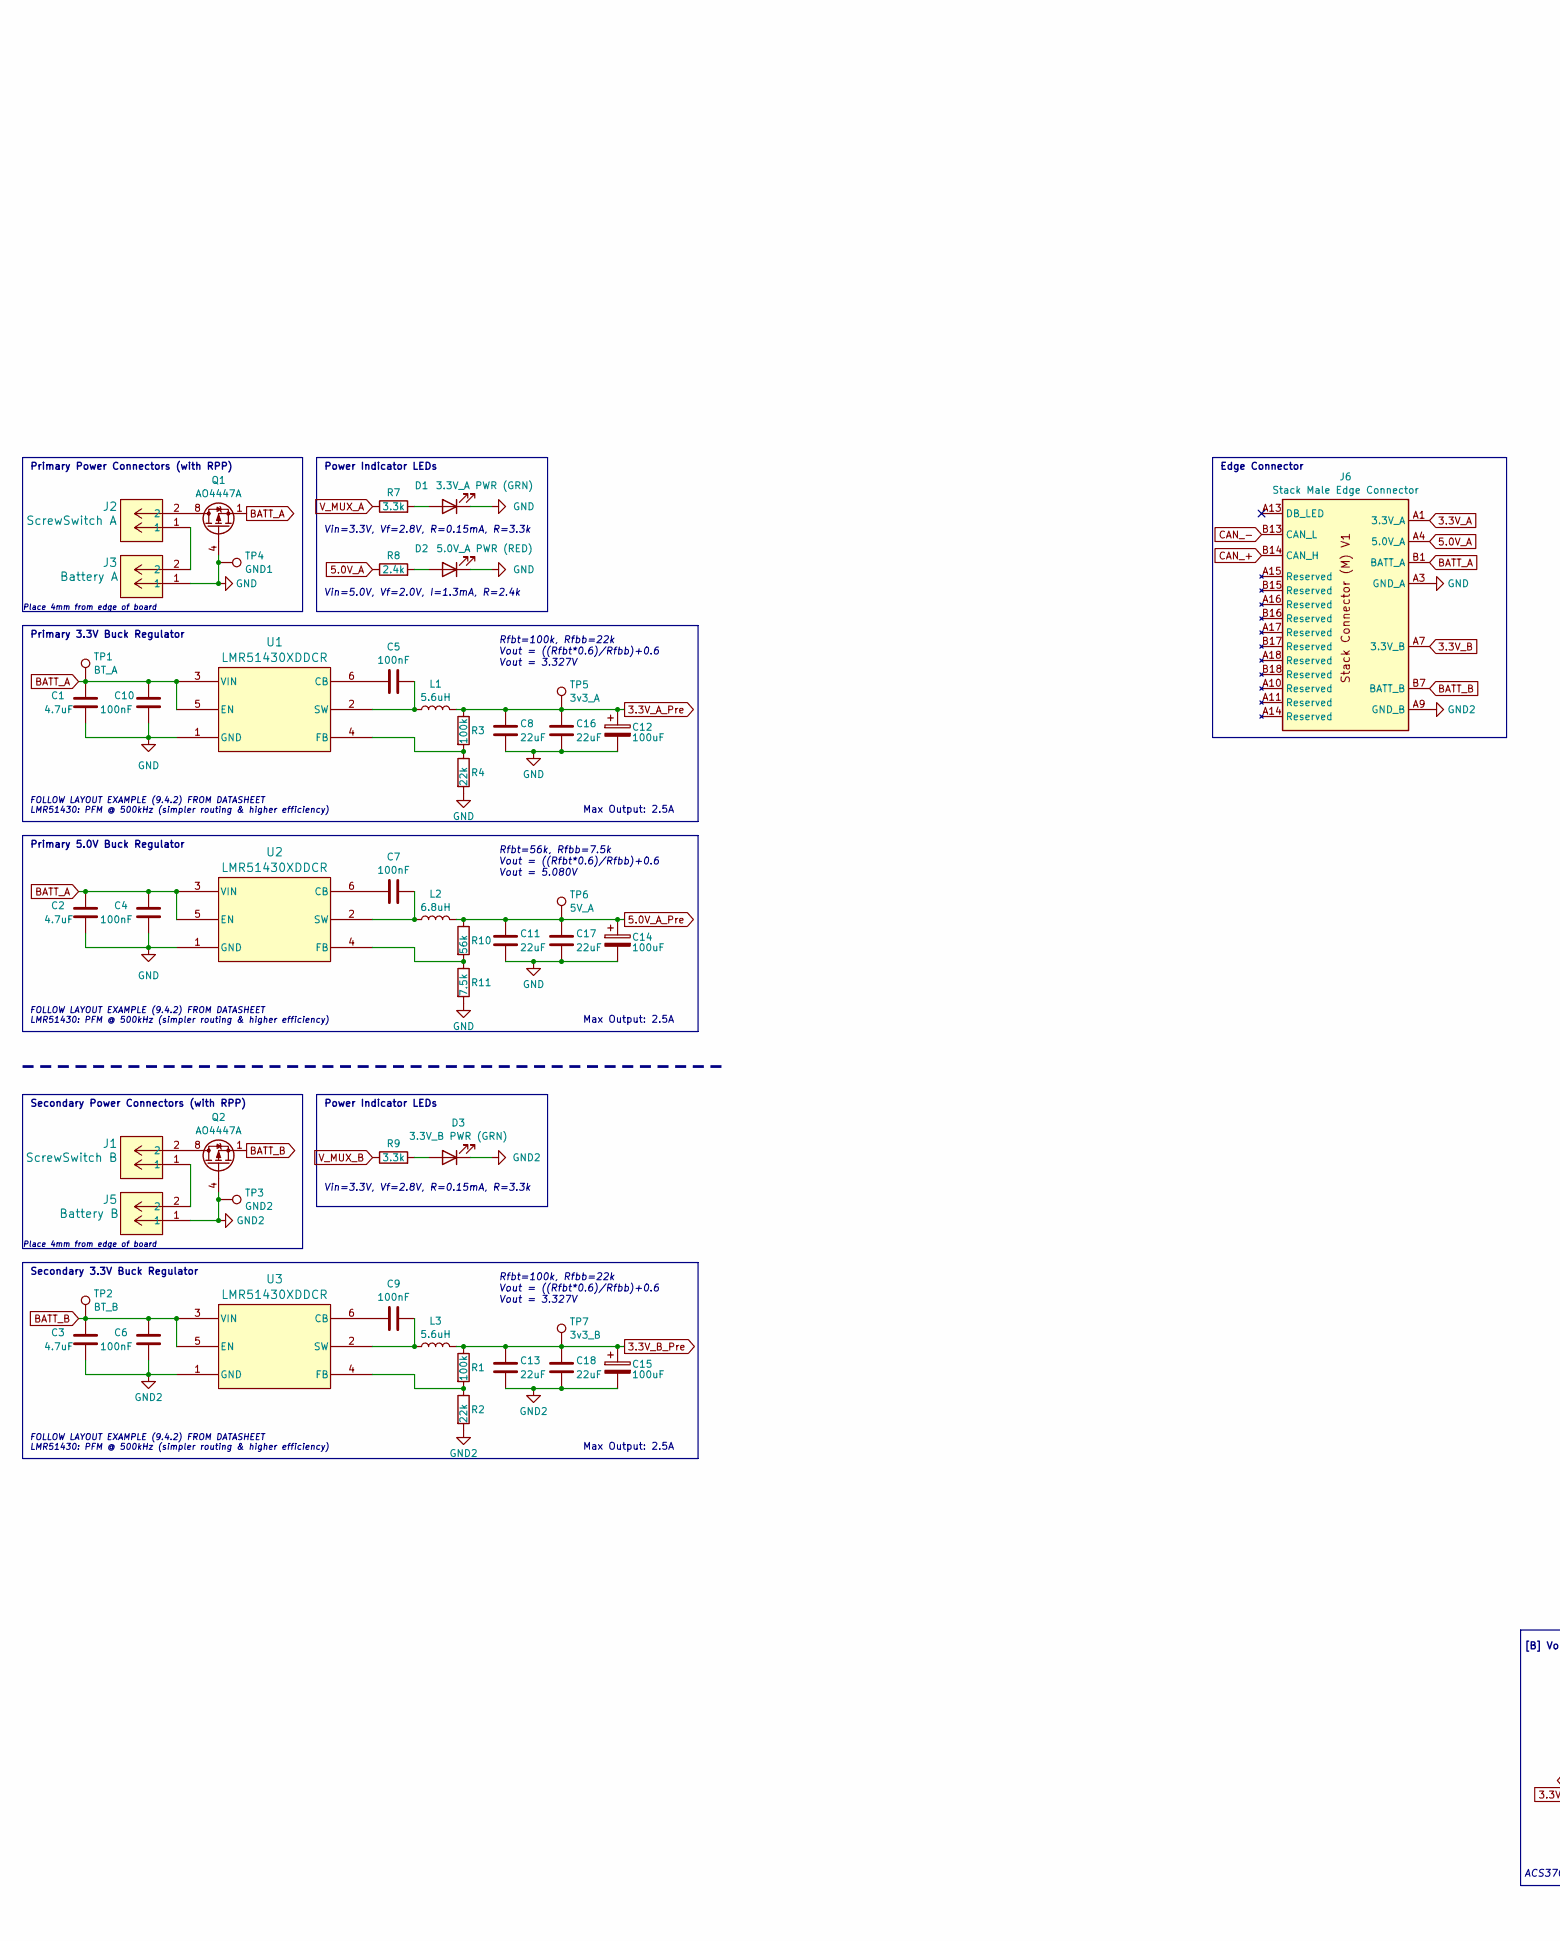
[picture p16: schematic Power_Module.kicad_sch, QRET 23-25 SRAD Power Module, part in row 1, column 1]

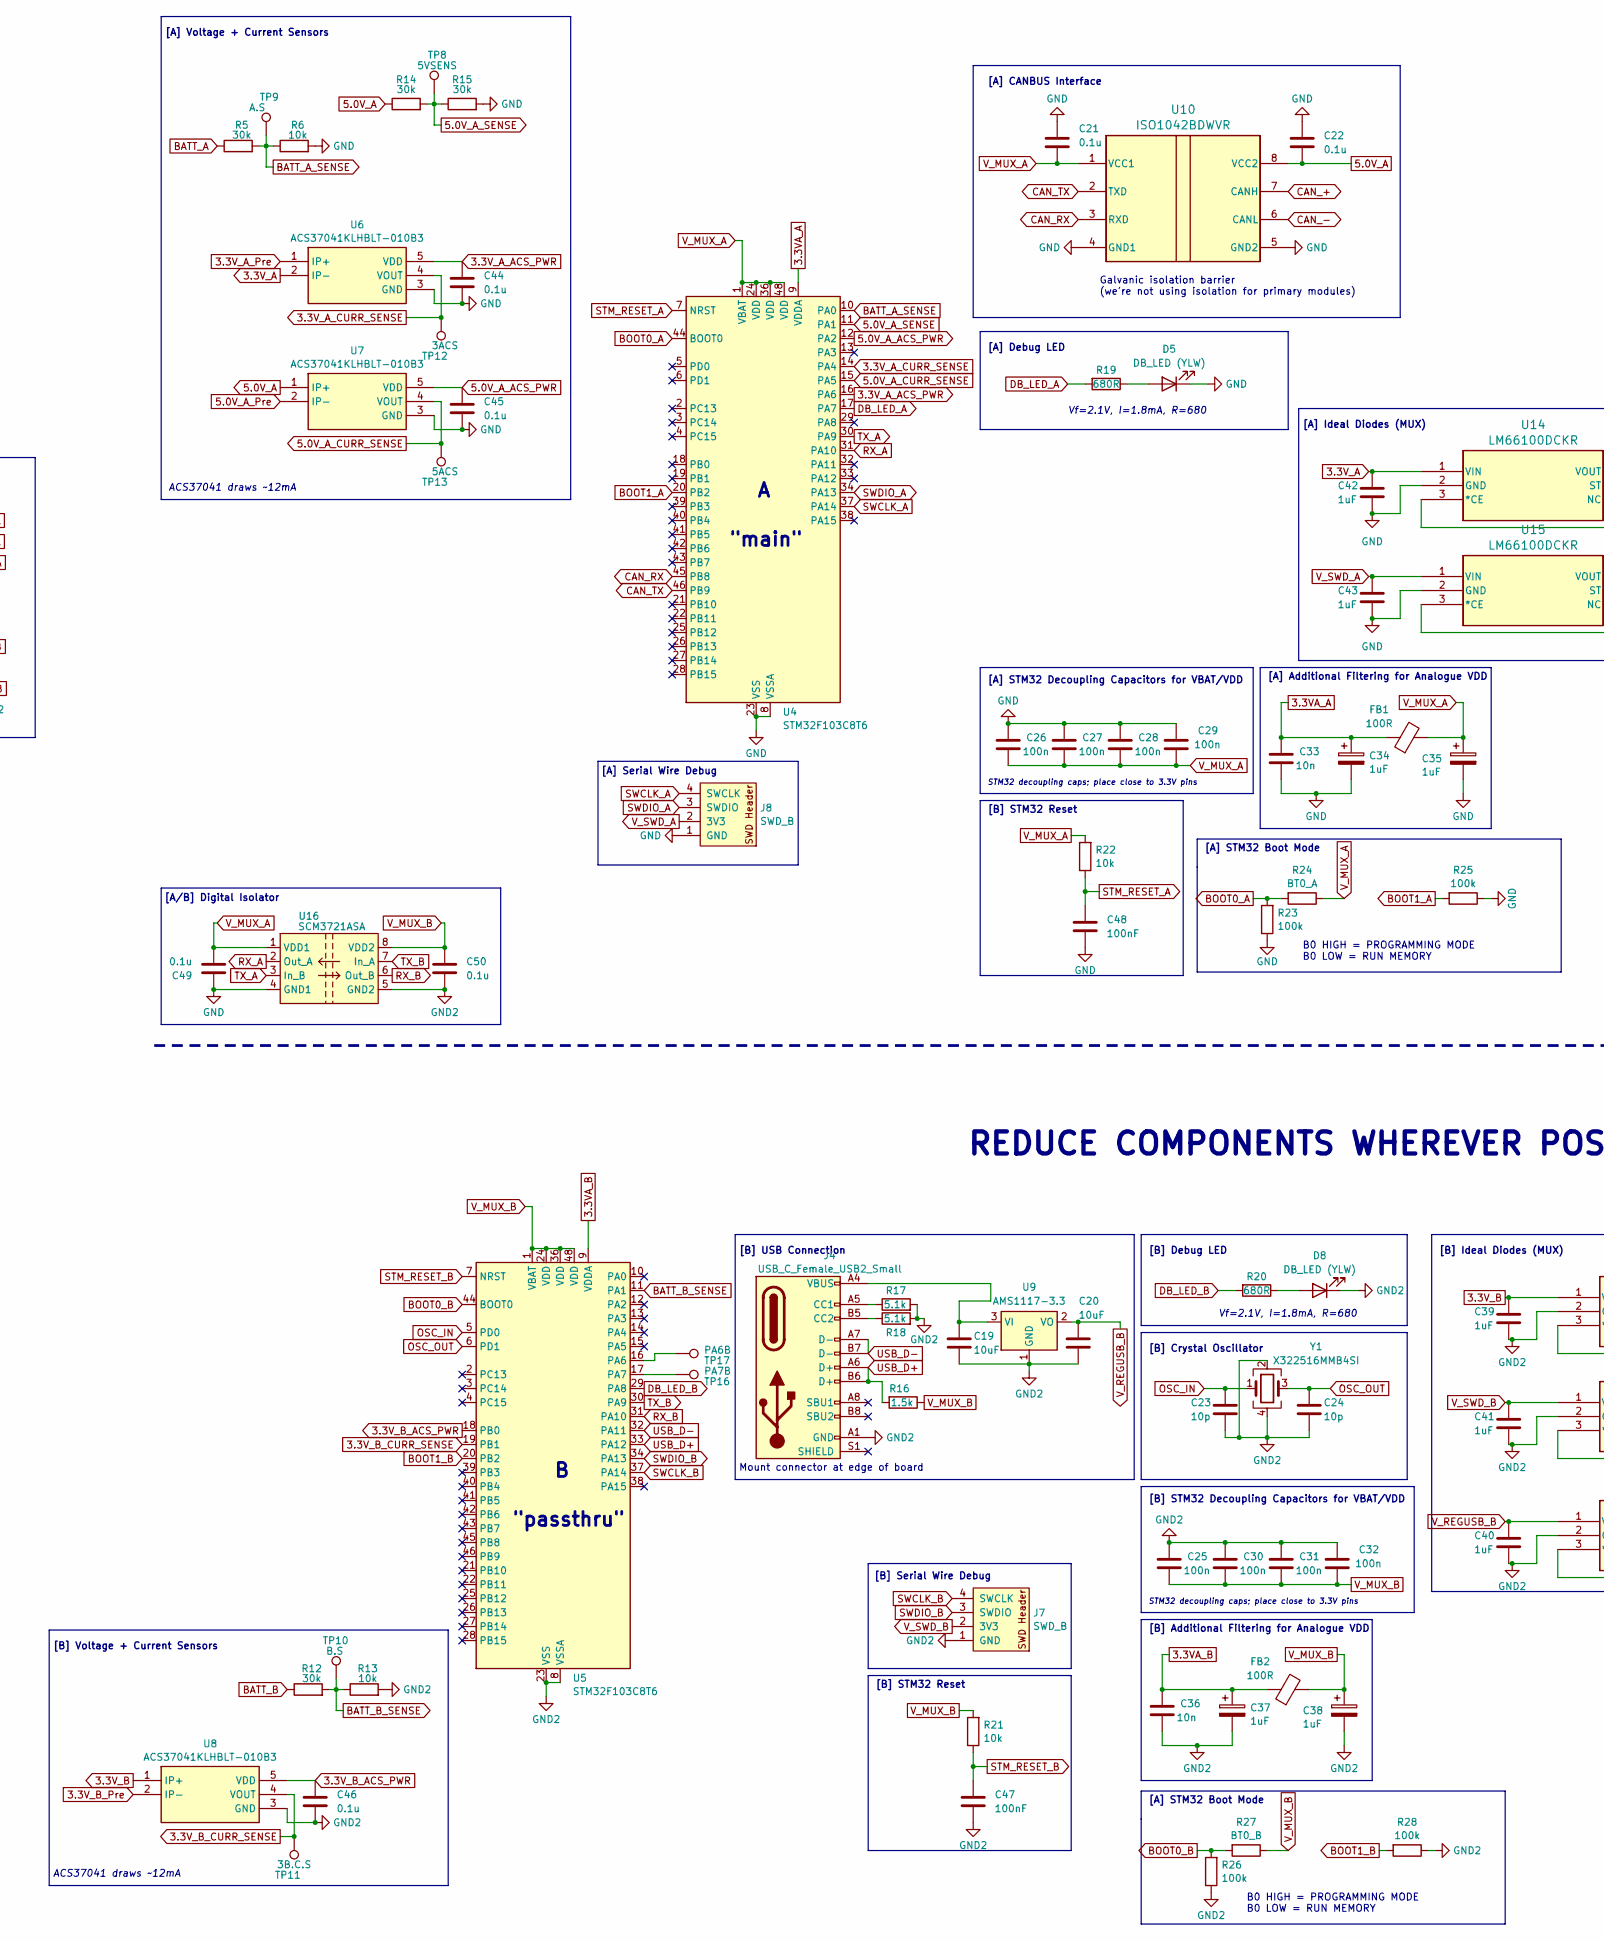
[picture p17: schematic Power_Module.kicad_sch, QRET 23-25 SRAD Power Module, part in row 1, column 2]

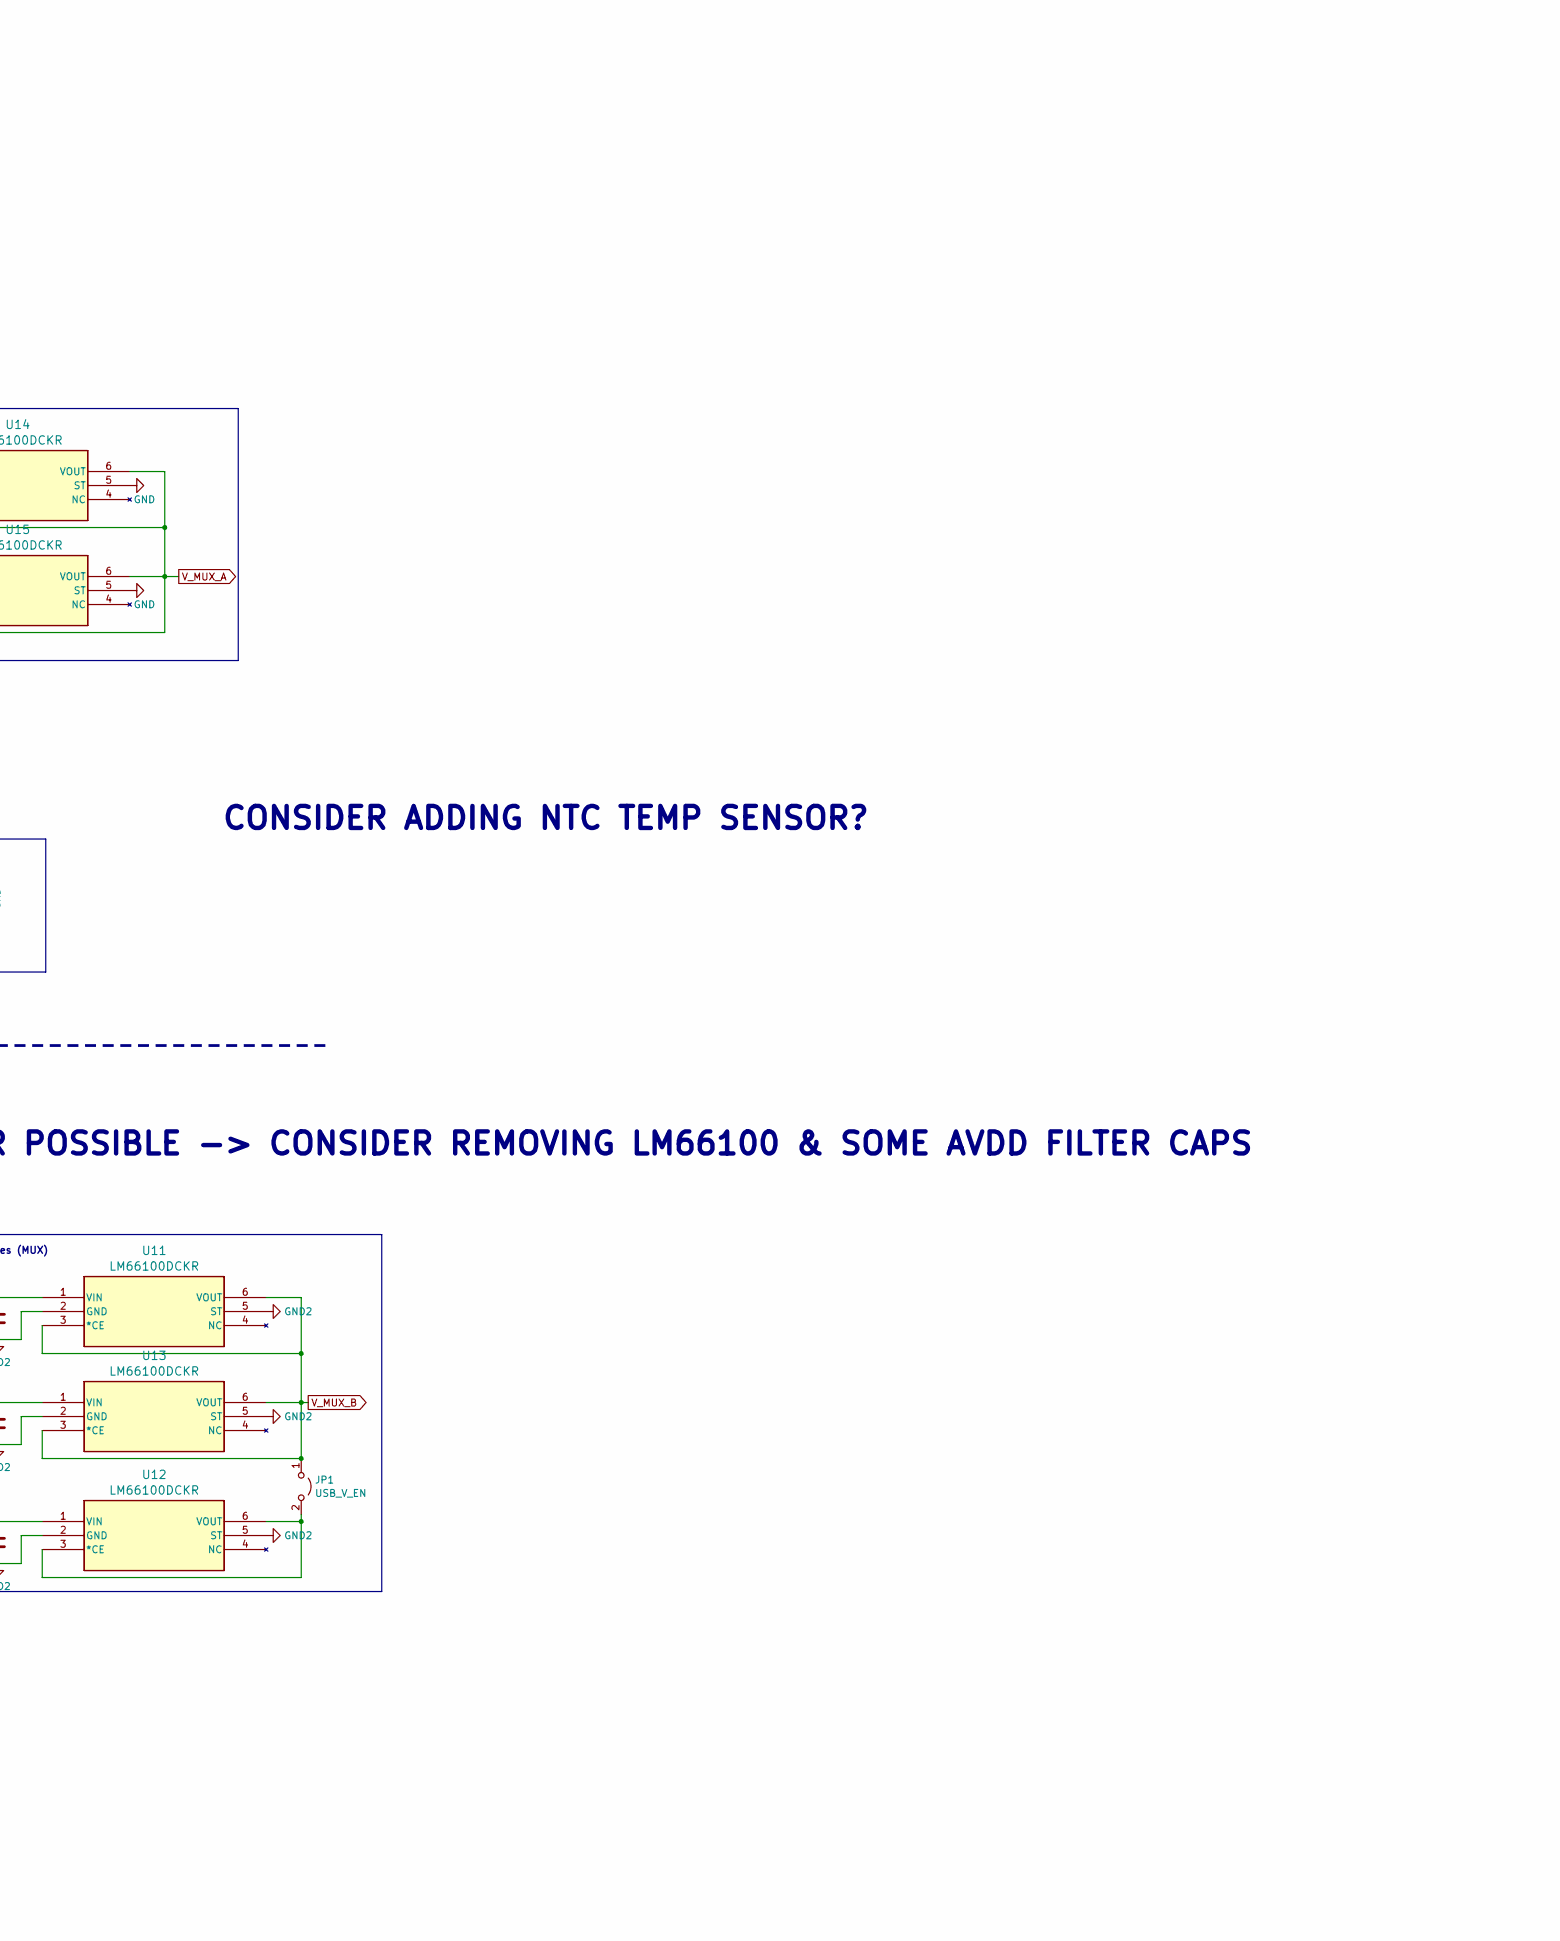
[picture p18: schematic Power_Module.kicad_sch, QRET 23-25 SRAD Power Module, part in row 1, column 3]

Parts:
C1, C2, C3: 4.7uF; C_0805_2012Metric; JLCPCB C1779
C4, C5, C6, C7, C9, C10, C47, C48: 100nF; C_0603_1608Metric; JLCPCB C14663
C8, C11, C13, C16, C17, C18: 22uF; C_0805_2012Metric; JLCPCB C45783
C12, C14, C15: 100uF; CP_Elec_6.3x5.9; Digikey 732-8419-1-ND
C19, C20: 10uF; C_0603_1608Metric; JLCPCB C96446
C21, C22, C44, C45, C46: 0.1u; C_0603_1608Metric; JLCPCB C14663
C23, C24: 10p; C_0603_1608Metric; JLCPCB C1634
C25, C26, C27, C28, C29, C30, C31, C32: 100n; C_0402_1005Metric; JLCPCB C1525
C33, C36: 10n; C_0603_1608Metric; JLCPCB C57112
C34, C35, C37, C38: 1uF; C_0805_2012Metric; JLCPCB C28323
C39, C40, C41, C42, C43: 1uF; C_0603_1608Metric; JLCPCB C15849
C49, C50: 0.1u; C_0603_1608Metric_Pad1.08x0.95mm_HandSolder; JLCPCB C14663
D1: 3.3V_A PWR (GRN); LED_0805_2012Metric; JLCPCB C2297
D2: 5.0V_A PWR (RED); LED_0805_2012Metric; JLCPCB C84256
D3: 3.3V_B PWR (GRN); LED_0805_2012Metric; JLCPCB C2297
D5, D8: DB_LED (YLW); LED_0603_1608Metric; JLCPCB C72038
FB1, FB2: 100R; R_0805_2012Metric; JLCPCB C1015
J1: ScrewSwitch B; CONN_2-1445057-2_TYCO; Digikey A33212CT-ND
J2: ScrewSwitch A; CONN_2-1445057-2_TYCO; Digikey A33212CT-ND
J3: Battery A; CONN_2-1445057-2_TYCO; Digikey A33212CT-ND
J4: USB_C_Female_USB2_Small; USB_C_DB-108PWB; JLCPCB C5178541
J5: Battery B; CONN_2-1445057-2_TYCO; Digikey A33212CT-ND
J6: Stack Male Edge Connector; BUS_PCIexpress_x1
J7, J8: SWD_B; SWD_PinHeader_1x04_P2.54mm_Horizontal_SMD; Digikey 952-3233-ND
JP1: USB_V_EN; SolderJumper-2_P1.3mm_Open_RoundedPad1.0x1.5mm
L1, L3: 5.6uH; L_Bourns_SRN8040TA; Digikey SDCHA1V8040-5R6-R
L2: 6.8uH; L_Bourns_SRN8040TA; Digikey HPC 8040NC-6R8M
Q1, Q2: AO4447A; SOIC-8_3.9x4.9mm_P1.27mm; JLCPCB C125867
R1, R3, R23, R25, R26, R28: 100k; R_0603_1608Metric; JLCPCB C25803
R2, R4: 22k; R_0603_1608Metric; JLCPCB C31850
R5, R12, R14, R15: 30k; R_0603_1608Metric; JLCPCB C22984
R6, R13, R21, R22: 10k; R_0603_1608Metric; JLCPCB C25804
R7, R9: 3.3k; R_0603_1608Metric; JLCPCB C22978
R8: 2.4k; R_0603_1608Metric; JLCPCB C22940
R10: 56k; R_0603_1608Metric; JLCPCB C23206
R11: 7.5k; R_0603_1608Metric; JLCPCB C23234
R16: 1.5k; R_0603_1608Metric; JLCPCB C22843
R17, R18: 5.1k; R_0603_1608Metric; JLCPCB C23186
R19, R20: 680R; R_0603_1608Metric; JLCPCB C23228
R24: BT0_A; R_0603_1608Metric_Pad0.98x0.95mm_HandSolder
R27: BT0_B; R_0603_1608Metric_Pad0.98x0.95mm_HandSolder
TP1: BT_A; TestPoint_Pad_2.0x2.0mm
TP2: BT_B; TestPoint_Pad_2.0x2.0mm
TP3: GND2; TestPoint_Pad_2.0x2.0mm
TP4: GND1; TestPoint_Pad_2.0x2.0mm
TP5: 3v3_A; TestPoint_Pad_2.0x2.0mm
TP6: 5V_A; TestPoint_Pad_2.0x2.0mm
TP7: 3v3_B; TestPoint_Pad_2.0x2.0mm
TP8: 5VSENS; TestPoint_Pad_1.5x1.5mm
TP9: A.S; TestPoint_Pad_1.5x1.5mm
TP10: B.S; TestPoint_Pad_1.5x1.5mm
TP11: 3B.C.S; TestPoint_Pad_1.5x1.5mm
TP12: 3ACS; TestPoint_Pad_1.5x1.5mm
TP13: 5ACS; TestPoint_Pad_1.5x1.5mm
TP16: PA7B; TestPoint_Pad_1.5x1.5mm
TP17: PA6B; TestPoint_Pad_1.5x1.5mm
U1, U2, U3: LMR51430XDDCR; SOT-23-6_Handsoldering; Digikey 296-LMR51430XDDCRCT-ND
U4, U5: STM32F103C8T6; LQFP-48_7x7mm_P0.5mm; JLCPCB C8734
U6, U7, U8: ACS37041KLHBLT-010B3; APS12628LLHALTBAP_HandSolder; Digikey 620-ACS37041KLHBLT-010B3CT-ND
U9: AMS1117-3.3; SOT-223-3_TabPin2; JLCPCB C6186
U10: ISO1042BDWVR; SOIC-8 ISO1042BDWV; JLCPCB C484409
U11, U12, U13, U14, U15: LM66100DCKR; SC-70-6_Handsoldering; JLCPCB C2869734
U16: SCM3721ASA; SOIC-8_3.9x4.9mm_P1.27mm; Digikey 2725-SCM3721ASACT-ND
Y1: X322516MMB4SI; Crystal_SMD_3225-4Pin_3.2x2.5mm; JLCPCB C13738

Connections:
3.3VA_A: C33.1, C34.1, FB1.1, U4.9 (VDDA)
3.3VA_B: C36.1, C37.1, FB2.1, U5.9 (VDDA)
3.3V_A: C42.1, J6.A1 (3.3V_A), J6.A2 (3.3V_A), U6.2 (IP-), U14.1 (VIN)
3.3V_A_ACS_PWR: C44.1, U4.16 (PA6), U6.5 (VDD)
3.3V_A_CURR_SENSE: TP12.1, U4.14 (PA4), U6.4 (VOUT)
3.3V_A_Pre: C8.1, C12.1, C16.1, L1.2, R3.1, TP5.1, U6.1 (IP+)
3.3V_B: C39.1, J6.A7 (3.3V_B), J6.A8 (3.3V_B), U8.1 (IP+), U11.1 (VIN)
3.3V_B_ACS_PWR: C46.1, U5.18 (PB0), U8.5 (VDD)
3.3V_B_CURR_SENSE: TP11.1, U5.19 (PB1), U8.4 (VOUT)
3.3V_B_Pre: C13.1, C15.1, C18.1, L3.2, R1.1, TP7.1, U8.2 (IP-)
5.0V_A: C22.2, J6.A4 (5.0V_A), J6.A5 (5.0V_A), R8.1, R14.1, U7.1 (IP+), U10.8 (VCC2)
5.0V_A_ACS_PWR: C45.1, U4.12 (PA2), U7.5 (VDD)
5.0V_A_CURR_SENSE: TP13.1, U4.15 (PA5), U7.4 (VOUT)
5.0V_A_Pre: C11.1, C14.1, C17.1, L2.2, R10.1, TP6.1, U7.2 (IP-)
5.0V_A_SENSE: R14.2, R15.1, TP8.1, U4.11 (PA1)
BATT_A: C1.1, C2.1, C4.1, C10.1, J6.B1 (BATT_A), J6.B2 (BATT_A), J6.B3 (BATT_A), Q1.1 (S), Q1.2 (S), Q1.3 (S), R5.1, TP1.1, U1.3 (VIN), U1.5 (EN), U2.3 (VIN), U2.5 (EN)
BATT_A_SENSE: R5.2, R6.1, TP9.1, U4.10 (PA0)
BATT_B: C3.1, C6.1, J6.B7 (BATT_B), J6.B8 (BATT_B), J6.B9 (BATT_B), Q2.1 (S), Q2.2 (S), Q2.3 (S), R12.1, TP2.1, U3.3 (VIN), U3.5 (EN)
BATT_B_SENSE: R12.2, R13.1, TP10.1, U5.11 (PA1)
BOOT0_A: R23.2, R24.2, U4.44 (BOOT0)
BOOT0_B: R26.2, R27.2, U5.44 (BOOT0)
BOOT1_A: R25.2, U4.20 (PB2)
BOOT1_B: R28.2, U5.20 (PB2)
CAN_+: J6.B14 (CAN_H), U10.7 (CANH)
CAN_-: J6.B13 (CAN_L), U10.6 (CANL)
CAN_RX: U4.45 (PB8), U10.3 (RXD)
CAN_TX: U4.46 (PB9), U10.2 (TXD)
DB_LED_A: R19.2, U4.17 (PA7)
DB_LED_B: R20.2, U5.29 (PA8)
GND: C1.2, C2.2, C4.2, C8.2, C10.2, C11.2, C12.2, C14.2, C16.2, C17.2, C21.1, C22.1, C26.1, C27.1, C28.1, C29.1, C33.2, C34.2, C35.2, C42.2, C43.2, C44.2, C45.2, C48.2, C49.1, D1.1 (K), D2.1 (K), D5.1 (K), J3.1, J6.A3 (GND_A), J6.A6 (GND_A), J6.B4 (GND_A), J6.B5 (GND_A), J6.B6 (GND_A), J8.1 (GND), Q1.4 (G), R4.2, R6.2, R11.2, R15.2, R23.1, R25.1, TP4.1, U1.1 (GND), U2.1 (GND), U4.8 (VSSA), U4.23 (VSS), U4.35 (VSS), U4.47 (VSS), U6.3 (GND), U7.3 (GND), U10.4 (GND1), U10.5 (GND2), U14.2 (GND), U14.5 (ST), U15.2 (GND), U15.5 (ST), U16.4 (GND1)
GND2: C3.2, C6.2, C13.2, C15.2, C18.2, C19.2, C20.2, C23.2, C24.2, C25.1, C30.1, C31.1, C32.1, C36.2, C37.2, C38.2, C39.2, C40.2, C41.2, C46.2, C47.2, C50.2, D3.1 (K), D8.1 (K), J4.A1 (GND), J4.A12 (GND), J4.B1 (GND), J4.B12 (GND), J5.1, J6.A9 (GND_B), J6.A12 (GND_B), J6.B10 (GND_B), J6.B11 (GND_B), J6.B12 (GND_B), J7.1 (GND), Q2.4 (G), R2.2, R13.2, R17.2, R18.2, R26.1, R28.1, TP3.1, U3.1 (GND), U5.8 (VSSA), U5.23 (VSS), U5.35 (VSS), U5.47 (VSS), U8.3 (GND), U9.1 (GND), U11.2 (GND), U11.5 (ST), U12.2 (GND), U12.5 (ST), U13.2 (GND), U13.5 (ST), U16.5 (GND2), Y1.2, Y1.4
unnamed: D1.2 (A), R7.2
unnamed: D2.2 (A), R8.2
unnamed: D3.2 (A), R9.2
unnamed: D5.2 (A), R19.1
unnamed: D8.2 (A), R20.1
unnamed: J1.1, J5.2
unnamed: J1.2, Q2.5 (D), Q2.6 (D), Q2.7 (D), Q2.8 (D)
unnamed: J2.1, J3.2
unnamed: J2.2, Q1.5 (D), Q1.6 (D), Q1.7 (D), Q1.8 (D)
unnamed: J4.A5 (CC1), R17.1
unnamed: J4.B5 (CC2), R18.1
unnamed: JP1.2 (B), U12.3 (*CE), U12.6 (VOUT)
unnamed: C5.2, U1.6 (CB)
unnamed: R3.2, R4.1, U1.4 (FB)
unnamed: C5.1, L1.1, U1.2 (SW)
unnamed: C7.2, U2.6 (CB)
unnamed: R10.2, R11.1, U2.4 (FB)
unnamed: C7.1, L2.1, U2.2 (SW)
unnamed: C9.2, U3.6 (CB)
unnamed: R1.2, R2.1, U3.4 (FB)
unnamed: C9.1, L3.1, U3.2 (SW)
unnamed: TP17.1, U5.16 (PA6)
unnamed: TP16.1, U5.17 (PA7)
unnamed: C19.1, J4.A4 (VBUS), J4.A9 (VBUS), J4.B4 (VBUS), J4.B9 (VBUS), U9.3 (VI)
OSC_IN: C23.1, U5.5 (PD0), Y1.1
OSC_OUT: C24.1, U5.6 (PD1), Y1.3
RX_A: U4.31 (PA10), U16.2 (Out_A)
RX_B: U5.31 (PA10), U16.6 (Out_B)
STM_RESET_A: C48.1, R22.1, U4.7 (NRST)
STM_RESET_B: C47.1, R21.1, U5.7 (NRST)
SWCLK_A: J8.4 (SWCLK), U4.37 (PA14)
SWCLK_B: J7.4 (SWCLK), U5.37 (PA14)
SWDIO_A: J8.3 (SWDIO), U4.34 (PA13)
SWDIO_B: J7.3 (SWDIO), U5.34 (PA13)
TX_A: U4.30 (PA9), U16.3 (In_B)
TX_B: U5.30 (PA9), U16.7 (In_A)
USB_D+: J4.A6 (D+), J4.B6 (D+), R16.2, U5.33 (PA12)
USB_D-: J4.A7 (D-), J4.B7 (D-), U5.32 (PA11)
V_MUX_A: C21.2, C26.2, C27.2, C28.2, C29.2, C35.1, C49.2, FB1.2, R7.1, R22.2, R24.1, U4.1 (VBAT), U4.24 (VDD), U4.36 (VDD), U4.48 (VDD), U10.1 (VCC1), U14.3 (*CE), U14.6 (VOUT), U15.3 (*CE), U15.6 (VOUT), U16.1 (VDD1)
V_MUX_B: C25.2, C30.2, C31.2, C32.2, C38.1, C50.1, FB2.2, JP1.1 (A), R9.1, R16.1, R21.2, R27.1, U5.1 (VBAT), U5.24 (VDD), U5.36 (VDD), U5.48 (VDD), U11.3 (*CE), U11.6 (VOUT), U13.3 (*CE), U13.6 (VOUT), U16.8 (VDD2)
V_REGUSB_B: C20.1, C40.1, U9.2 (VO), U12.1 (VIN)
V_SWD_A: C43.1, J8.2 (3V3), U15.1 (VIN)
V_SWD_B: C41.1, J7.2 (3V3), U13.1 (VIN)

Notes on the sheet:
Place 4mm from edge of board
Max Output: 2.5A
Primary Power Connectors (with RPP)
[B] Voltage + Current Sensors
B0 HIGH = PROGRAMMING MODE B0 LOW = RUN MEMORY
STM32 decoupling caps; place close to 3.3V pins
[A] Voltage + Current Sensors
Primary 5.0V Buck Regulator
[B] Debug LED
Primary 3.3V Buck Regulator
Vf=2.1V, I=1.8mA, R=680
"main"
Galvanic isolation barrier (we're not using isolation for primary modules)
[B] Crystal Oscillator
ACS37041 draws ~12mA
[B] STM32 Reset
Secondary Power Connectors (with RPP)
Vin=3.3V, Vf=2.8V, R=0.15mA, R=3.3k
FOLLOW LAYOUT EXAMPLE (9.4.2) FROM DATASHEET LMR51430: PFM @ 500kHz (simpler routing & higher efficiency)
Rfbt=56k, Rfbb=7.5k Vout = ((Rfbt*0.6)/Rfbb)+0.6 Vout = 5.080V
Mount connector at edge of board
Power Indicator LEDs
CONSIDER ADDING NTC TEMP SENSOR?
[B] Ideal Diodes (MUX)
Vin=5.0V, Vf=2.0V, I=1.3mA, R=2.4k
[B] Serial Wire Debug
Rfbt=100k, Rfbb=22k Vout = ((Rfbt*0.6)/Rfbb)+0.6 Vout = 3.327V
[A/B] Digital Isolator
"passthru"
[A] STM32 Boot Mode
[A] CANBUS Interface
[B] Additional Filtering for Analogue VDD
REDUCE COMPONENTS WHEREVER POSSIBLE -> CONSIDER REMOVING LM66100 & SOME AVDD FILTER CAPS
[B] STM32 Decoupling Capacitors for VBAT/VDD
[A] Additional Filtering for Analogue VDD
Edge Connector
[B] USB Connection
[A] Ideal Diodes (MUX)
Secondary 3.3V Buck Regulator
[A] Serial Wire Debug

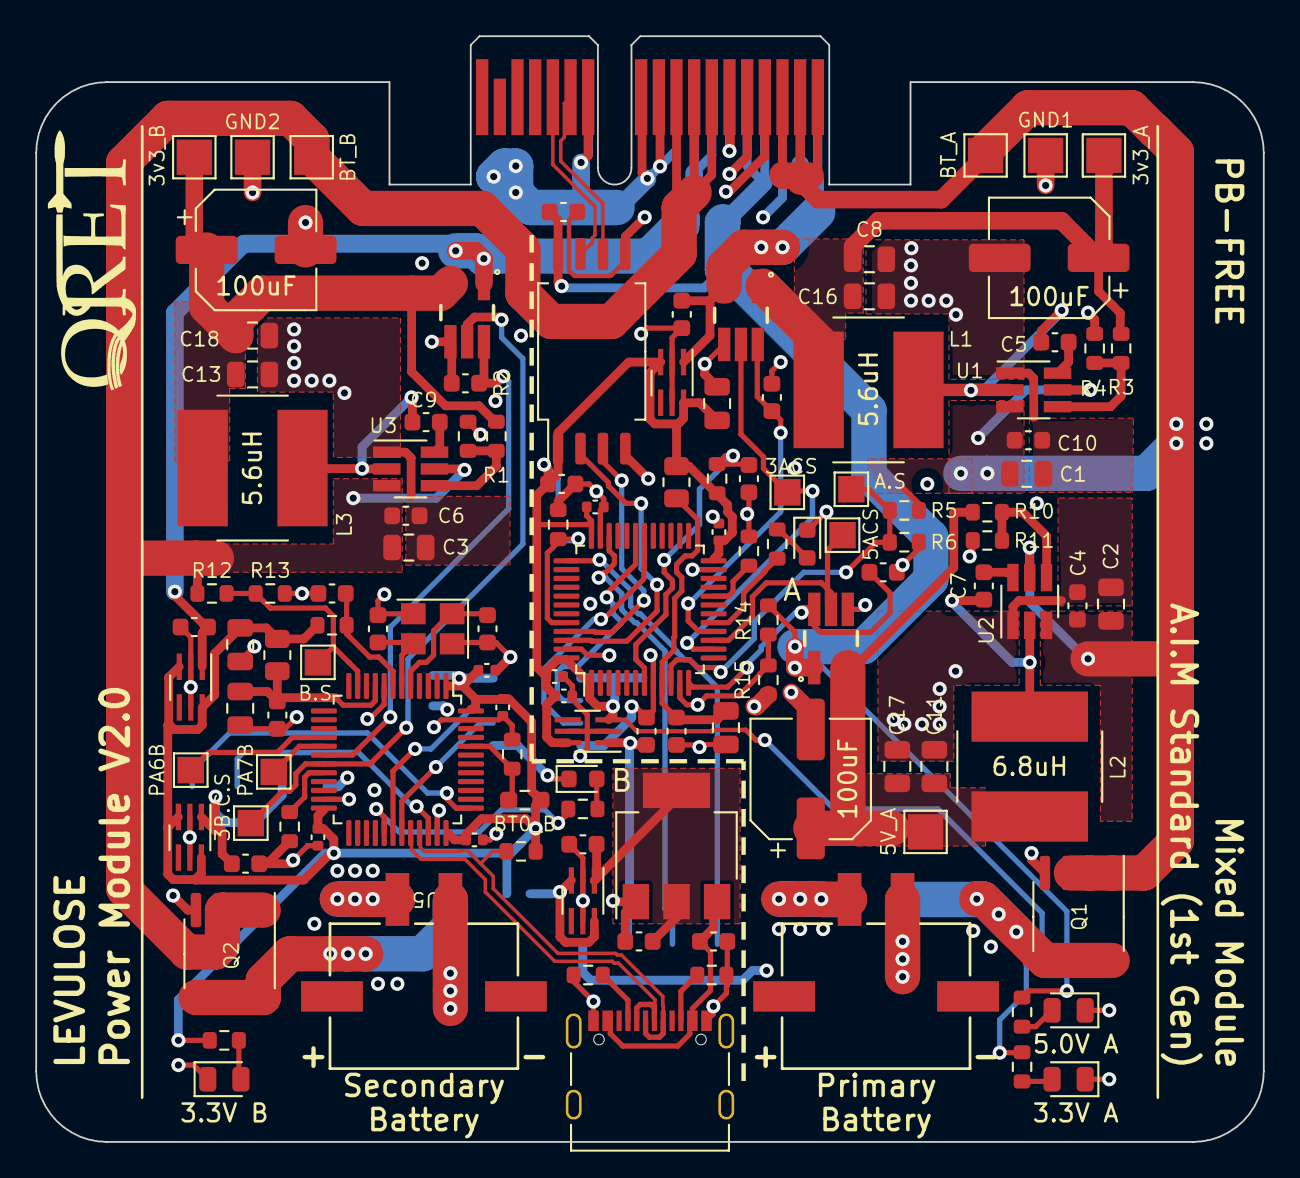
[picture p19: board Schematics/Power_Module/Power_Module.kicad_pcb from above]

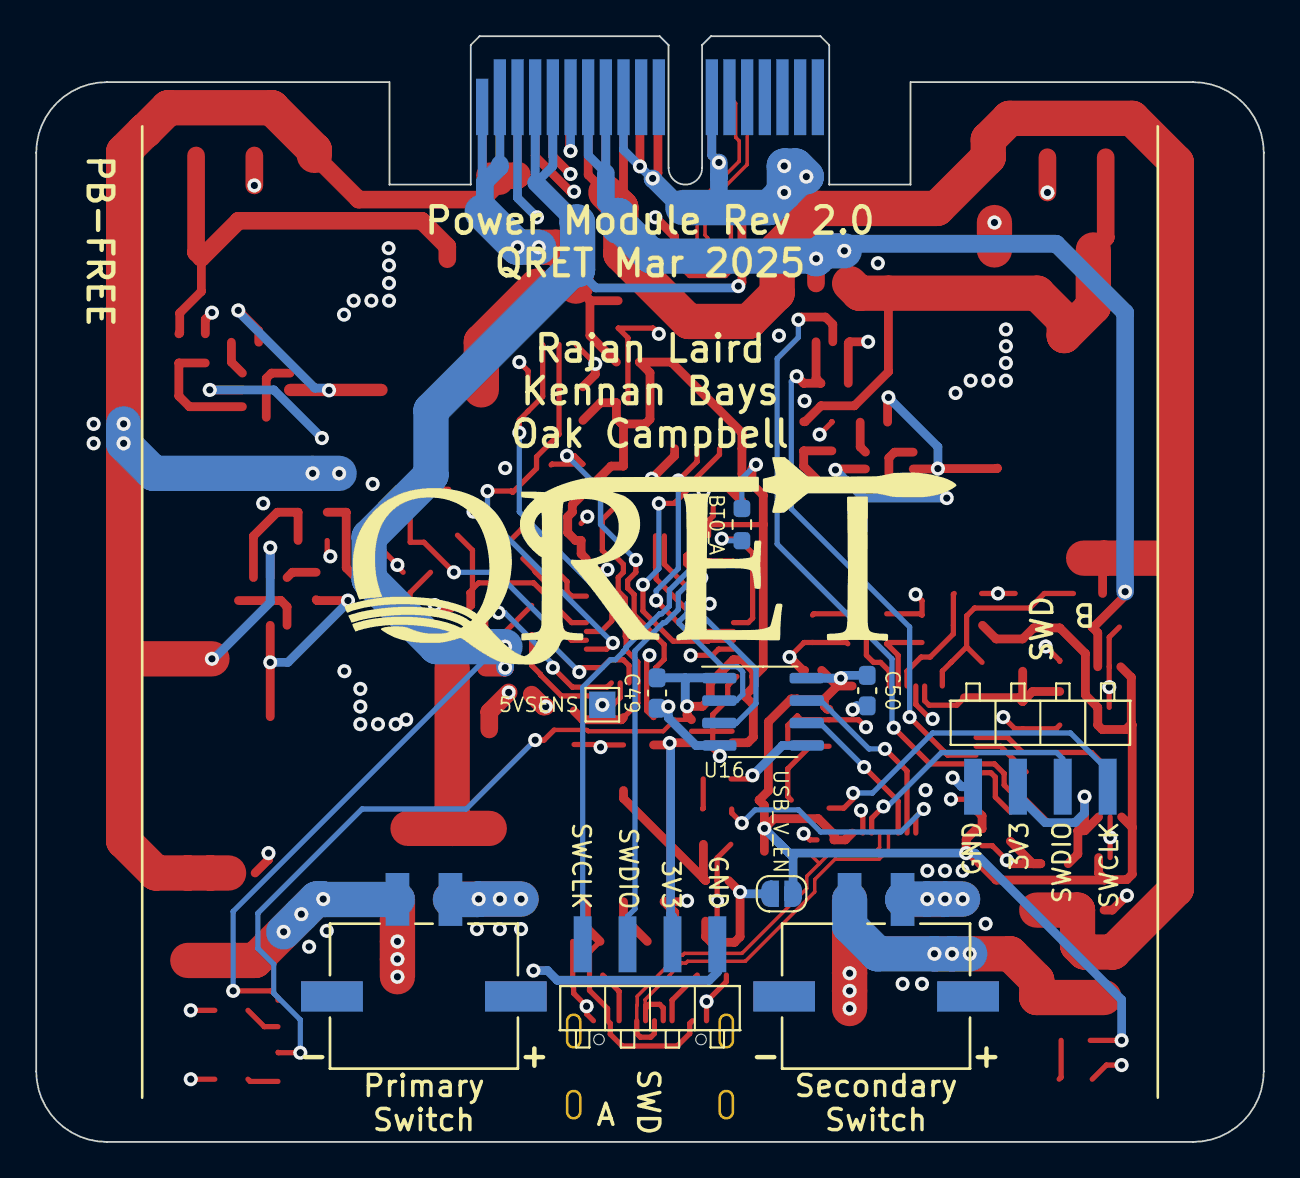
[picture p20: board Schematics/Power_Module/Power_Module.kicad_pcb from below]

Board: 4 copper layers, 69.5 x 62.6 mm, 131 parts (10 on the bottom side), 74 nets.

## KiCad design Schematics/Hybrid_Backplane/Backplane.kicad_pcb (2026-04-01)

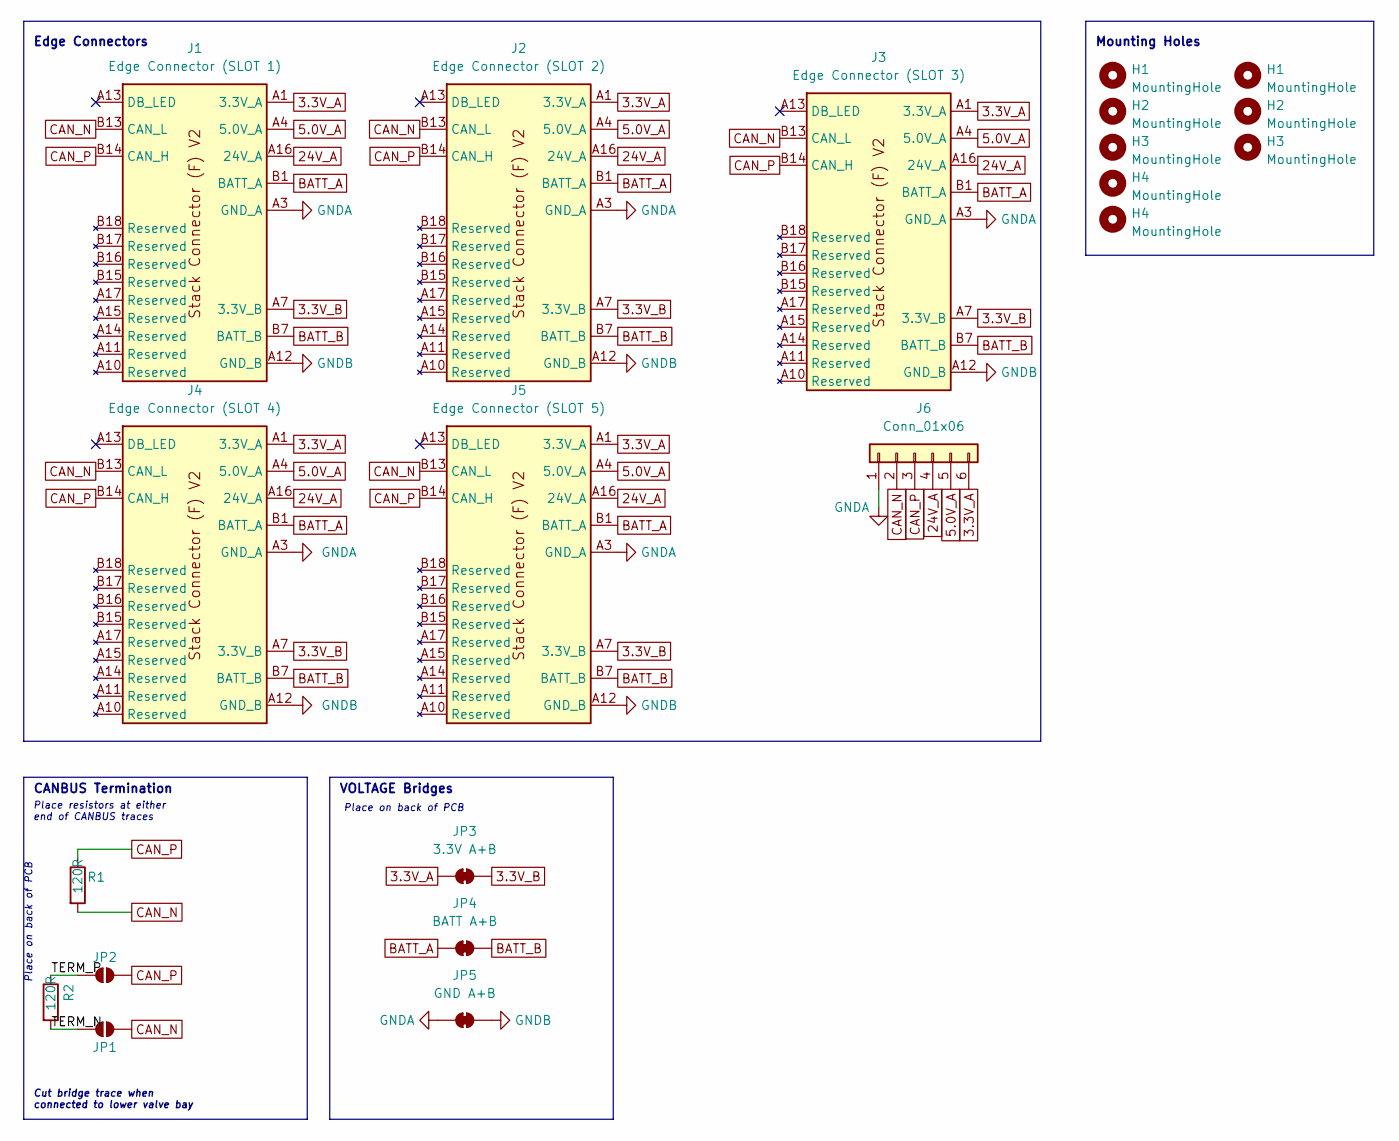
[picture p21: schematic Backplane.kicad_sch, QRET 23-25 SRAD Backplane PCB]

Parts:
H1, H2, H3, H4: MountingHole; MountingHole_3.2mm_M3_ISO14580_Pad
J1: Edge Connector (SLOT 1); AMPHENOL_10018784-10210TLF
J2: Edge Connector (SLOT 2); AMPHENOL_10018784-10210TLF
J3: Edge Connector (SLOT 3); AMPHENOL_10018784-10210TLF
J4: Edge Connector (SLOT 4); AMPHENOL_10018784-10210TLF
J5: Edge Connector (SLOT 5); AMPHENOL_10018784-10210TLF
J6: Conn_01x06; CONN_SD-105314-100_06_MOL; Digikey WM1821-ND
JP1: N JMP; SolderJumper-2_P1.3mm_Open_RoundedPad1.0x1.5mm
JP2: P JMP; SolderJumper-2_P1.3mm_Open_RoundedPad1.0x1.5mm
JP3: 3.3V A+B; SolderJumper-2_P1.3mm_Bridged2Bar_RoundedPad1.0x1.5mm
JP4: BATT A+B; SolderJumper-2_P1.3mm_Bridged2Bar_RoundedPad1.0x1.5mm
JP5: GND A+B; SolderJumper-2_P1.3mm_Bridged2Bar_RoundedPad1.0x1.5mm
R1, R2: 120R; R_0805_2012Metric_Pad1.20x1.40mm_HandSolder; Digikey A129738CT-ND

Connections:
3.3V_A: J1.A1 (3.3V_A), J1.A2 (3.3V_A), J2.A1 (3.3V_A), J2.A2 (3.3V_A), J3.A1 (3.3V_A), J3.A2 (3.3V_A), J4.A1 (3.3V_A), J4.A2 (3.3V_A), J5.A1 (3.3V_A), J5.A2 (3.3V_A), J6.6, JP3.1 (A)
3.3V_B: J1.A7 (3.3V_B), J1.A8 (3.3V_B), J2.A7 (3.3V_B), J2.A8 (3.3V_B), J3.A7 (3.3V_B), J3.A8 (3.3V_B), J4.A7 (3.3V_B), J4.A8 (3.3V_B), J5.A7 (3.3V_B), J5.A8 (3.3V_B), JP3.2 (B)
5.0V_A: J1.A4 (5.0V_A), J1.A5 (5.0V_A), J2.A4 (5.0V_A), J2.A5 (5.0V_A), J3.A4 (5.0V_A), J3.A5 (5.0V_A), J4.A4 (5.0V_A), J4.A5 (5.0V_A), J5.A4 (5.0V_A), J5.A5 (5.0V_A), J6.5
24V_A: J1.A16 (24V_A), J1.A18 (24V_A), J2.A16 (24V_A), J2.A18 (24V_A), J3.A16 (24V_A), J3.A18 (24V_A), J4.A16 (24V_A), J4.A18 (24V_A), J5.A16 (24V_A), J5.A18 (24V_A), J6.4
/TERM_N: JP1.2 (B), R2.2
/TERM_P: JP2.2 (B), R2.1
BATT_A: J1.B1 (BATT_A), J1.B2 (BATT_A), J1.B3 (BATT_A), J2.B1 (BATT_A), J2.B2 (BATT_A), J2.B3 (BATT_A), J3.B1 (BATT_A), J3.B2 (BATT_A), J3.B3 (BATT_A), J4.B1 (BATT_A), J4.B2 (BATT_A), J4.B3 (BATT_A), J5.B1 (BATT_A), J5.B2 (BATT_A), J5.B3 (BATT_A), JP4.1 (A)
BATT_B: J1.B7 (BATT_B), J1.B8 (BATT_B), J1.B9 (BATT_B), J2.B7 (BATT_B), J2.B8 (BATT_B), J2.B9 (BATT_B), J3.B7 (BATT_B), J3.B8 (BATT_B), J3.B9 (BATT_B), J4.B7 (BATT_B), J4.B8 (BATT_B), J4.B9 (BATT_B), J5.B7 (BATT_B), J5.B8 (BATT_B), J5.B9 (BATT_B), JP4.2 (B)
CAN_N: J1.B13 (CAN_L), J2.B13 (CAN_L), J3.B13 (CAN_L), J4.B13 (CAN_L), J5.B13 (CAN_L), J6.2, JP1.1 (A), R1.2
CAN_P: J1.B14 (CAN_H), J2.B14 (CAN_H), J3.B14 (CAN_H), J4.B14 (CAN_H), J5.B14 (CAN_H), J6.3, JP2.1 (A), R1.1
GNDA: J1.A3 (GND_A), J1.A6 (GND_A), J1.B4 (GND_A), J1.B5 (GND_A), J1.B6 (GND_A), J2.A3 (GND_A), J2.A6 (GND_A), J2.B4 (GND_A), J2.B5 (GND_A), J2.B6 (GND_A), J3.A3 (GND_A), J3.A6 (GND_A), J3.B4 (GND_A), J3.B5 (GND_A), J3.B6 (GND_A), J4.A3 (GND_A), J4.A6 (GND_A), J4.B4 (GND_A), J4.B5 (GND_A), J4.B6 (GND_A), J5.A3 (GND_A), J5.A6 (GND_A), J5.B4 (GND_A), J5.B5 (GND_A), J5.B6 (GND_A), J6.1, JP5.1 (A)
GNDB: J1.A9 (GND_B), J1.A12 (GND_B), J1.B10 (GND_B), J1.B11 (GND_B), J1.B12 (GND_B), J2.A9 (GND_B), J2.A12 (GND_B), J2.B10 (GND_B), J2.B11 (GND_B), J2.B12 (GND_B), J3.A9 (GND_B), J3.A12 (GND_B), J3.B10 (GND_B), J3.B11 (GND_B), J3.B12 (GND_B), J4.A9 (GND_B), J4.A12 (GND_B), J4.B10 (GND_B), J4.B11 (GND_B), J4.B12 (GND_B), J5.A9 (GND_B), J5.A12 (GND_B), J5.B10 (GND_B), J5.B11 (GND_B), J5.B12 (GND_B), JP5.2 (B)

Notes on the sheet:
Cut bridge trace when connected to lower valve bay
CANBUS Termination
Place on back of PCB
Place resistors at either end of CANBUS traces
VOLTAGE Bridges
Mounting Holes
Edge Connectors

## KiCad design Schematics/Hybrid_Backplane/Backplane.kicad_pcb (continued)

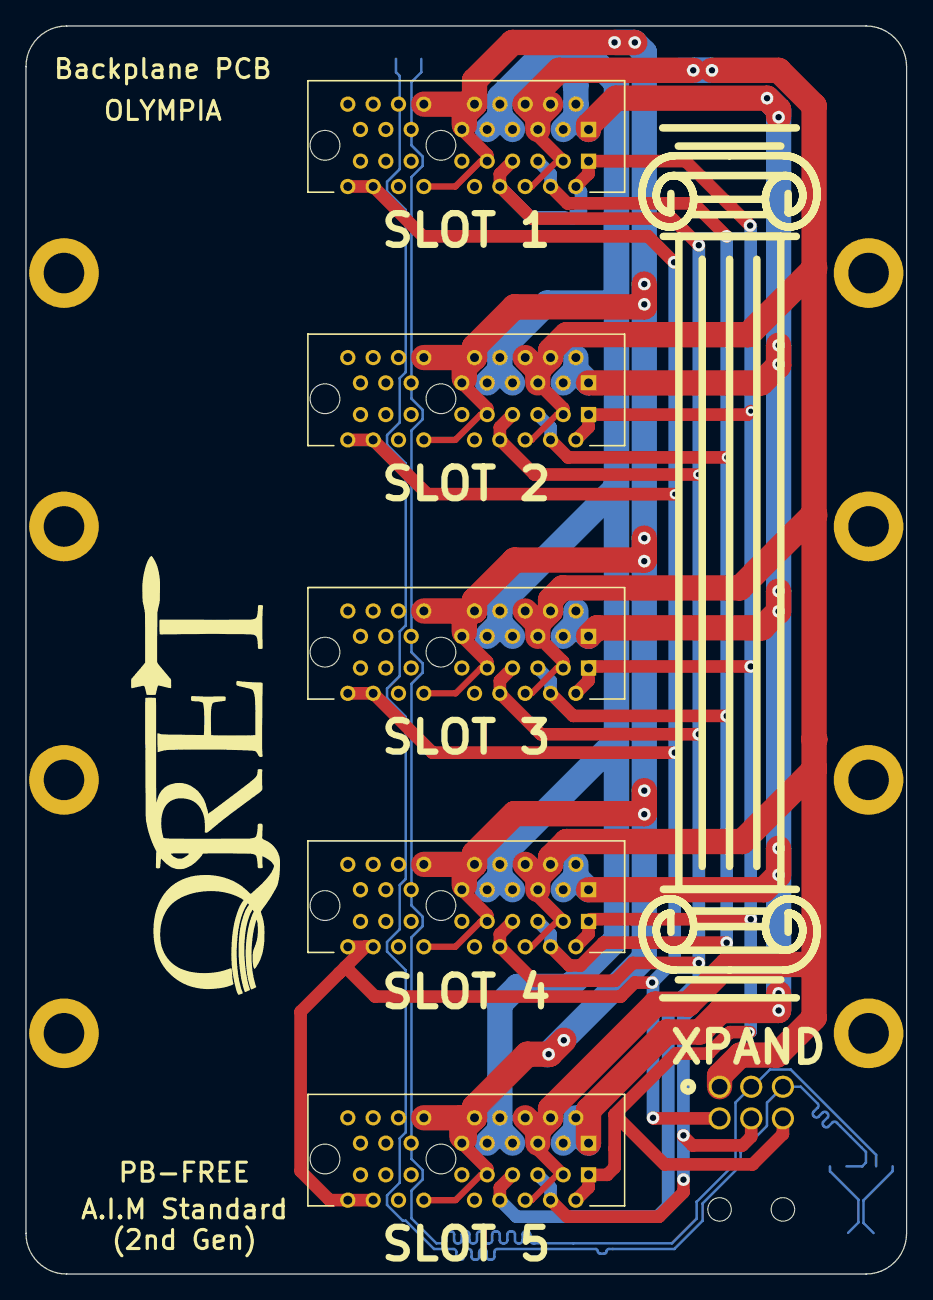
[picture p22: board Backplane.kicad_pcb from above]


Board: 2 copper layers, 69.5 x 98.5 mm, 21 parts (8 on the bottom side), 12 nets.

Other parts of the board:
H5, H6, H7, H8: MountingHole; MountingHole_3.2mm_M3_ISO14580_Pad

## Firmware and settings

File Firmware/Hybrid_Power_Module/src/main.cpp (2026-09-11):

#include "node.h"

#include <IWatchdog.h>
#include <logger.h>
#include <SoftwareSerial.h>
#include <SPI.h>

#include <aim_file_system.h>
#include <aim_flight_recorder.h>
#ifndef FLIGHT_BUILD
#include <aim_console.h>
#endif

static constexpr uint32_t kWatchdogTimeoutUs  = 10000000U; // 10 seconds timeout
static constexpr uint8_t  kMaxRxFramesPerLoop = 8U;

static AimCanHardware g_canHw(node::kCanBaud, CAN1);
static AimNetwork g_aim(&g_canHw, node::kSource);
static SoftwareSerial g_serial(pins::kSerialRx, pins::kSerialTx);
static Logger g_log(g_serial, static_cast<uint8_t>(node::kSource), LogLevel::INFO);

// Flash on SPI2: MOSI=PB15, MISO=PB14, SCLK=PB13, CS=PB12 (kFlashReset in pinouts.h).
static SPIClass g_flashSpi(pins::kSpiMosi, pins::kSpiMiso, pins::kSpiSclk);
static SpiNorFlashDriver g_flashDriver(pins::kFlashReset, g_flashSpi);
static AimFileSystem g_fs(&g_flashDriver);
static AimFlightRecorder g_recorder(g_fs, kLogCols, kLogOriginRefresh, kLogMaxSize, kLogHeaders);

static void serviceCanRx(void) {
  const uint32_t nowMs = millis();
  for (uint8_t i = 0U; i < kMaxRxFramesPerLoop; i++) {
    aim::Msg m = {};
    if (!g_aim.receive(m)) break;
    nodeOnRx(m, nowMs);
  }
}

#ifndef FLIGHT_BUILD
static void hookStatus(Stream& out) {
  out.print("name=");
  out.print(node::kName);
  out.print(" logMask=0x");
  out.print(static_cast<unsigned>(g_log.filterMask()), HEX);
  out.print(" syncedMs=");
  out.print(static_cast<unsigned long>(g_aim.syncedMillis()));
  out.print(" version=");
  out.print(aim::kNetworkVersionString);
  out.print(" schema=");
  out.print(static_cast<unsigned>(aim::kSchemaVersion));
  out.print(" build=");
  out.print(__DATE__);
  out.print(" ");
  out.println(__TIME__);
}
#endif  // FLIGHT_BUILD

void setup(void) {
  g_serial.begin(node::kSerialBaud);
  g_logger = &g_log;
  g_log.setFilterMask(static_cast<uint8_t>(LogLevel::INFO));  // INFO only
  LOG_INFO("Boot %s source=%u", node::kName, static_cast<unsigned>(node::kSource));

  // Power is a Sensor/State publisher and TimeSync consumer.
  if (!g_aim.begin(aim::classBit(aim::Class::Time) |
                   aim::classBit(aim::Class::Heartbeat))) {
    LOG_ERROR("CAN init failed");
  }

  if (!g_fs.begin()) {
    LOG_WARN("Filesystem mount failed");
  } else if (!g_recorder.begin()) {
    LOG_WARN("Recorder init failed");
  } else {
    LOG_INFO("Flash ready");
  }

#ifndef FLIGHT_BUILD
  uint8_t nodeHookCount = 0U;
  const AimConsoleHook* nodeHooks = nodeConsoleHooks(nodeHookCount);

  static AimConsoleHook combinedHooks[8];
  uint8_t totalHooks = 0;
  combinedHooks[totalHooks++] = {'s', "status", hookStatus};
  for (uint8_t i = 0; i < nodeHookCount && totalHooks < 8; i++) {
    combinedHooks[totalHooks++] = nodeHooks[i];
  }
  aimConsoleInit(g_serial, g_fs, g_recorder, node::kName, combinedHooks, totalHooks);
#endif

  nodeInit();

  IWatchdog.begin(kWatchdogTimeoutUs);
  LOG_INFO("Watchdog ready (%lus timeout)", static_cast<unsigned long>(kWatchdogTimeoutUs / 1000000U));

#ifndef FLIGHT_BUILD
  g_serial.println("Console ready. d=enter debug");
#endif
}

void loop(void) {
  const uint32_t nowMs = millis();

  serviceCanRx();
  nodeUpdate(nowMs);
  if (!aimConsoleIsActive()) {
    nodeServiceLog(nowMs, g_recorder);
  }
  nodeServiceCanTx(nowMs, g_aim);
  g_aim.service(nowMs, nodeCurrentState(), nodeErrorBits());

#ifndef FLIGHT_BUILD
  aimConsoleService();
#endif

  IWatchdog.reload();
}

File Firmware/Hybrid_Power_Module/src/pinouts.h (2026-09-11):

#ifndef PINOUTS_H
#define PINOUTS_H

#include <Arduino.h> // needed for PB/A# pin assignment
#include <cstdint>

// pinouts.h - APOLLO Hybrid Power Module V1.0 2025/2026 (STM32F103CBT6) pin map.
namespace pins {

// --- Serial (USB-UART Bridge; TX/RX are swapped on the PCB) ---
//  !!! Fix in next board spin !!!
//  Use software serial
constexpr uint8_t kSerialTx = PB10; // USART_TX -> USB_RX
constexpr uint8_t kSerialRx = PB11; // USART_RX <- USB_TX

// --- CAN bus ---
constexpr uint8_t kCanRx = PB8;
constexpr uint8_t kCanTx = PB9;

// --- Flash interface (SPI) ---
constexpr uint8_t kFlashReset = PB12;
constexpr uint8_t kSpiSclk   = PB13;
constexpr uint8_t kSpiMiso   = PB14;
constexpr uint8_t kSpiMosi   = PB15;

// --- Voltage and current sensing ---
constexpr uint8_t kBatterySense    = PA0;
constexpr uint8_t kGseSense        = PB1;
constexpr uint8_t k24VCurrentSense = PB0;
constexpr uint8_t k5VSense         = PA1;
// Power enable for 3.3v current sense
constexpr uint8_t k3V3AcsPower     = PA4;
constexpr uint8_t k3V3CurrentSense = PA2;
// Power enable for 5v current sense
// !!! DO NOT POWER ON (using wrong current sense could break mcu)
constexpr uint8_t k5VAcsPower      = PA6;
constexpr uint8_t k5VCurrentSense  = PA5;

// --- LEDs ---
constexpr uint8_t kDebugLed = PA7;

}

#endif // PINOUTS_H

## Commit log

2026-01-07 Cleanup of branch for importing into dedicated repo - dedicated for power deliver systems - added direct local paths to datasheets in schematic - added all datasheets related to projects
    [10118194-0001LF-USB.step, 8890445_SWD_PINS.stp, ACS37041KLHBLT-010B3.stp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]
2026-02-04 init commit of hybrid backplane with new extension connector - using bridges to merge POWER trace B with A for altimter - add 120ohm termination bridge to allow CAN to work standlone
    [430450602.stp, Backplane.kicad_pcb, Backplane.kicad_sch]
2026-02-09 init commit of power board hybrid revision
    [Power_Module.kicad_pcb, Power_Module.kicad_sch]
2026-02-09 updated backplane length to fit in stack design - need to route traces to extension connector
    [Backplane.kicad_pcb, Backplane.kicad_sch]
2026-02-21 init commit of power design, with Bucks completed - started Boost design
    [Power_Module.kicad_sch, TPS61175PWPR.step, VLS5045EX-100M-H.step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]
2026-02-22 cleaned up boost pdf & lcsc and noted next steps
    [power.kicad_sch]
2026-02-22 adding power ORing circuit
    [Power_Module.kicad_sch, battery_charger.kicad_sch, mcu.kicad_sch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]
2026-02-22 opted out of charger in design
    [battery_charger.kicad_sch]
2026-02-26 Backplane Trace
    [Backplane.kicad_pcb]
2026-03-02 start of my own backplane layout
    [Backplane.kicad_pcb, Backplane.kicad_sch]
2026-03-04 add equations for Boost and instructions for buck design changes
    [power.kicad_sch]
2026-03-04 fixed skew for CAN bus
    [Backplane.kicad_pcb]
2026-03-05 Update power.kicad_sch
    Changed frequency to 500 000Hz and updated schematics (not the new footprint)
    [power.kicad_sch]
2026-03-05 3.3V inductor changed to 27uF 3.6A
    [mcu.kicad_sch, power.kicad_sch]
2026-03-05 Update buck designs for 500kHz, prioritize efficiency
    [SRR1260A.STP, VLS5045EX-100M-H.step, VLS6045EX-680M-H.step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]
2026-03-05 updated buck input caps voltage rating to 50V
    [power.kicad_sch]
2026-03-10 complete clamping and rpp for 24v gse source - chose 24v source ORing mosfet
    [Power_Module.kicad_pcb, mcu.kicad_sch, power.kicad_sch]
2026-03-11 ongoing equation for boost calculations
    [power.kicad_sch]
2026-03-18 Reverted Commit
    [power.kicad_sch]
2026-03-18 Update Text
    [power.kicad_sch]
2026-03-19 finalized buck and boost designs,
    [power.kicad_sch]
2026-03-19 minor review of part numbers - NEED major review of buck and boost design
    [power.kicad_sch]
2026-03-20 started layout design - added shunt based 24V current sensing
    [Power_Module.kicad_pcb, mcu.kicad_sch, power.kicad_sch]
2026-03-21 current progress on power board
    [Power_Module.kicad_pcb, Power_Module.kicad_sch, mcu.kicad_sch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]
2026-03-22 major layout progress, still need to place MCU
    [Power_Module.kicad_pcb, Power_Module.kicad_sch, mcu.kicad_sch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]
2026-03-23 continueing layout, confirmed all devices will fix - need to add bulk rail caps - fixed issue in oring logic
    [Power_Module.kicad_pcb, Power_Module.kicad_sch, mcu.kicad_sch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]
2026-03-23 New Backplane
    [Backplane.kicad_pcb]
2026-03-23 confirm layout, confirm everything fits
    [Power_Module.kicad_pcb, Power_Module.kicad_sch, mcu.kicad_sch]
2026-03-24 completed all power traces, finalizing signal traces
    [Power_Module.kicad_pcb, Power_Module.kicad_sch, mcu.kicad_sch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]
2026-03-24 continuing to finish signal traces, added extra decouplping caps near PCIE
    [Power_Module.kicad_pcb, mcu.kicad_sch]
2026-03-25 finished all traces, confirmed major DRC errors - need to fix silkscreen - review needed and LCSC verification
    [Power_Module.kicad_pcb, mcu.kicad_sch, power.kicad_sch]
2026-03-25 updated todo lists
    [Power_Module.kicad_pcb, Power_Module.kicad_sch]
2026-03-26 Made Minor Updates
    - Update Silk Screen to Reflect 2026 Year
    - Connected CAN_P Line to Connectors
    - Moved R2 Slightly Away from the Edge
    - Fixed DRC Error With J6
    Still To Do:
    - Name Board
    - Update Silkscreen
    [Backplane.kicad_pcb]
2026-03-26 Forgot to save Resistor Move
    [Backplane.kicad_pcb]
2026-03-26 hybrid backplane ready for order
    [10018784-10210TLF.step, 430450602.stp, Backplane.kicad_pcb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]
2026-03-26 hybrid power board, with preserved OG Power board - still hybrid still needs review and silkscreen
    [8890445_SWD_PINS.stp, ACS37041KLHBLT-010B3.stp, CONN_2-1445057-2_AMP.step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]
2026-03-27 fix part number and bom formation, update mostfet based on stock
    [Power_Module.kicad_pcb, mcu.kicad_sch, power.kicad_sch]
2026-03-27 restored non hybrid backplane
    [430450602.stp, Backplane.kicad_pcb, Backplane.kicad_sch]
2026-03-27 finished power board silkscreen, needs final review before approval
    [ISO1042BDWVR.step, ISO1044BDR.stp, Power_Module.kicad_pcb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]
2026-03-28 minor updates to part numbers and silkscreen
    [Power_Module.kicad_pcb, mcu.kicad_sch, power.kicad_sch]
2026-03-28 Rename backplane diretory for consitency
    [10018784-10210TLF.step, 430450602.stp, Backplane.kicad_pcb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]
2026-03-28 fixed voltage divder for GSE 24v
    [Power_Module.kicad_pcb, power.kicad_sch]
2026-03-28 changed current sense and switched to bidirectional TVS for GSE power
    [Power_Module.kicad_pcb, mcu.kicad_sch, power.kicad_sch]
2026-03-29 add nano connector for xpand, adjust routing
    [1053141106.stp, Backplane.kicad_pcb, Backplane.kicad_sch]
2026-03-30 final board submitted to cart
    [Power_Module.kicad_pcb, mcu.kicad_sch, power.kicad_sch]
2026-03-30 minor fixes to silkscreen
    [Power_Module.kicad_pcb, mcu.kicad_sch, power.kicad_sch]
2026-03-30 using copper poor for 5v and 3.3v buck sw
    [Power_Module.kicad_pcb, power.kicad_sch]
2026-06-14 fw(av-power): add Hybrid_Power_Module v0.6.x scaffold
    Establishes node.*/pinouts.h layout following AIM Network v0.6.x workspace
    convention. Stubs out nodeInit/nodeUpdate/nodeServiceCanTx pending power-board
    pin definition (UART, SPI-flash, sensing rails all TBD). CAN only — no serial
    logger until UART pins are confirmed.
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2026-06-14 feat(power): implement dynamic state/error reporting and battery telemetry
    [main.cpp, node.cpp, pinouts.h]
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2026-06-18 Hybrid_Power: pass nowMs into service()
    Match the updated AimNetwork::service(nowMs, state, errorBits) signature.
    [main.cpp]
2026-06-21 Hybrid_Power: node convention cleanup and naming alignment
    Apply lowerCamelCase naming, explicit Job init, and static combinedHooks
    fix consistent with the other five nodes.
    [main.cpp, node.cpp]
2026-07-07 fix: Updates after testing, for next revision
    - add current limiting to GSE RPP zener shunt
    - switched 5v current sensor
    - flipped CAN and UART polarity
    - add 3.3v reference to CAN transceiver
    [Power_Module.kicad_pcb, Power_Module.kicad_sch, mcu.kicad_sch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]
2026-07-16 Update RPP circuit to reflect R31 and R32 values used for fix
    [power.kicad_sch]
2026-08-07 fw(av-power): migrate Hybrid_Power_Module to aim_network v0.7.x
    v0.7.x removes aim_can_driver.{h,cpp} and replaces it with the
    AimCanHardware alias, resolved per-architecture inside aim_network.h
    (AimStm32CanCore here). The constructor signature is unchanged, so the
    swap is mechanical. Everything else the protocol changed -- flat 29-bit
    ID layout, Msg::b[4] -> b[8], the 16-bit offsetMs timestamp encoding --
    is absorbed inside AimNetwork::send/receive, and classBit() simply moved
    to aim_catalog.h in the same aim:: namespace. node.cpp needs no changes.
    Also adopts node::kSource (matching the av-recovery/av-prop convention)
    and moves the bus to 1 Mbps per the v0.7.0 protocol.
    Note this is a f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
    [main.cpp]
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2026-08-18 fix(power): remove the LowPower event entirely (no threshold, no broadcast, no Fault state)
    Battery voltage stays on CAN as BattVolt telemetry; nothing on the bus acts on LowPower
    any more, and the 11.1 V single-sample trip could safe valves spuriously. Reverts my
    earlier restore of the periodic refresh.
    [node.cpp]
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
